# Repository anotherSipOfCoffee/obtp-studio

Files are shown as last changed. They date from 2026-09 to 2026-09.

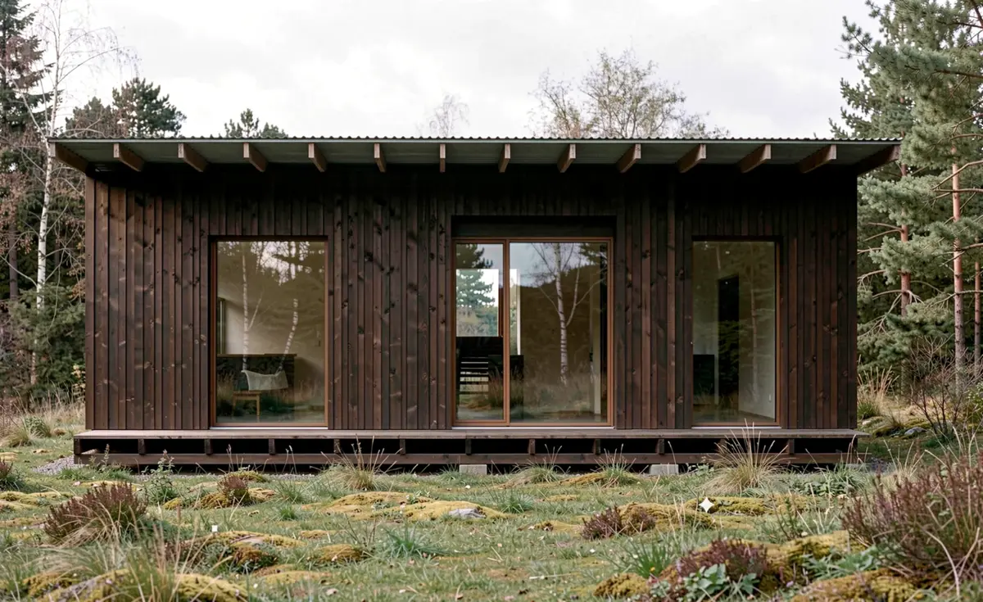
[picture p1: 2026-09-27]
dist/marketing/assets/s1-front.webp

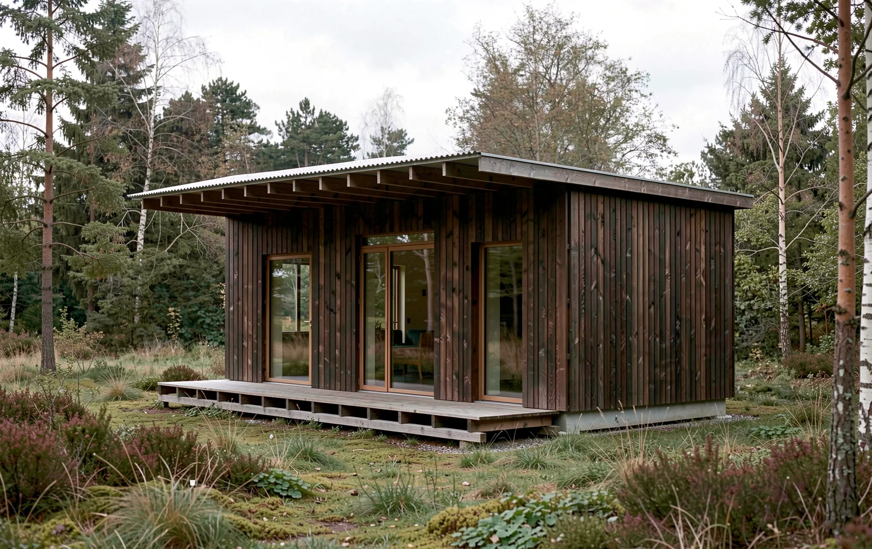
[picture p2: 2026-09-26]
dist/v3/images/studio-03.webp

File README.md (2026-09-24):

# OBTP Studio

Three variations in the selector: v1 original conceptual reference, v2 WikiHouse, v3 independent OBTP Cassette 01 research prototype. The default remains v2.

System is the source for v2/v3 geometry and assembly rules. system.lock.json pins its exact commit; tools/prepare_system.py verifies the checked-out commit and copies its dist tree to dist/system-source. Do not commit that reproducible copy. Studio v1 remains byte-identical to the pre-task reference.

Read 00_START_HERE.md and AGENTS.md for the Drive master / GitHub development policy. Changes are on dev/obtp-independent-v1-20260923; main/live are unchanged. The new read-only Check Studio development variations workflow builds and tests a downloadable preview, without deploying.

The existing Pages workflow publishes on main or manual execution. It is preserved but not authorized to run in this task. For local inspection of a prepared preview, serve its dist folder with python -m http.server 8765 --directory dist and open http://localhost:8765/#v3.

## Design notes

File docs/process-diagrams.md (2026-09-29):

# Process section — September 2026

Approved four diagrams originate in the owner-supplied `diagrams.3dm`. The SVG files retain projected model coordinates, uniform scale, original camera direction and arrangement; they are not AI-redrawn buildings. Diagram 01 has white, dark grey and light grey blocks. Other diagrams have neutral monochrome faces. Only geometry display and website copy changed. No change to System pin, presets, geometry outputs or PDF generation.

The four steps describe the intended product route, with production/delivery still in development. The page retains its wider development and occupancy notes. LT/EN shares the configurator language preference. Homepage defaults to Lithuanian when no preference is saved.

Configurator shows two active presets and four locked parameter previews: size, extension, sloped roof (No selected), terrace (Yes selected). Both selected and alternative parameter buttons are hatched. Public model values remain unchanged.

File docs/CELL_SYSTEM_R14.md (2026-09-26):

# Integrated cell system and previous-system comparison

Studio consumes the R14 canonical System export. The current model uses 900 × 1200 planning cells and a regular support lattice shared by building and terrace. Geometry and comparison quantities are generated in Python, never in Studio JavaScript.

Additional information now compares the selected new and previous configurations: structural footprint, wall assemblies, physical wood parts, geometric wood types and foundation support count. Links open actual model-derived plans for both. The named sizes no longer imply equal footprints; the comparison says so explicitly. No cost, speed or manufacturing-equivalence claims are made.

Existing configuration choice controls, Lithuanian default, white model presentation, disabled PDFs and two website roof options remain. Studio v1 and WikiHouse are preserved. Source pin changes require the System suite and Studio/browser checks; native Rhino acceptance and structural engineering remain separate.

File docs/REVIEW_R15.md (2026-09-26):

# studio 9120 — R16 review

Pins canonical System 0df918f23ed5cebb24259104ad7aa93918e5c1a9. System PR #20 and Studio PR #37 remain unmerged and unpublished.

Shared catalogue candidates: original 459 → first cells 381 → revised 319 (30.5% below original). Sauna 296 → 251 → 227 (23.3%); Studio 246 → 226 → 216 (12.2%). The 75% goal is not achieved. Previous opening revision: 358; geometry repairs alone: 370; shared cuts: 319 at unchanged footprints (13.8%). Same-first-cell-footprint revised: 340, separating resizing from construction changes.

Default complete M buildings: Sauna 121 types / 1063 primary pieces; Studio 137 / 1354. Shared cuts add 109 / 137 pieces and three / four default-building types versus repairs only. Catalogue reuse has an assembly cost. Facade remains visible and separately scheduled; no additional category is excluded.

Standard bays and plans remain; alternative grids created more variants. Selected lining extensions, facade battens and roof rails share supported lengths. Both widths remain 2400 mm. Terrace boards run consistently through returns. Repairs clear deck trims, niche facade overlaps and Studio glazing/head intersections. Connections and structural capacities remain unverified.

System review-r15/SHARED_KIT.md contains results, trials, primary source guidance and engineering holds. Its generated standalone review includes model-derived plans, six interactive models and cut comparisons. Studio consumes pinned outputs without duplicate geometry formulas.

Customer branding is studio 9120. Retain Lithuanian default, Plokščias, existing parameters, Main-first navigation, disabled PDF, no gable and normal GH preview. Drive and Architecture unchanged.

Final System suite: 51 tests passed, including supported joints, all-wood clashes, glazing clearances and export contracts. Non-deploying Studio CI compiles 216 browser configurations and 12 portable Rhino exports, tests browser behaviour and captures screenshots. Native Rhino/GH and engineering acceptance remain open.

The workflow provides studio-development-preview and visual-review artifacts. Serve the complete dist directory locally; generated review/index.html opens standalone. Production hosting is unchanged.

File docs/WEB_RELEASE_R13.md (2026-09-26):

# Website controls and PDF pause — 2026-09-26

Owner requests supersede the earlier three-roof/PDF release policy:

- Disable website PDF generation and show all four PDF downloads as disabled.
  The GH download also excludes PDF proofs. SVG plans and Rhino models remain.
- Remove the gable roof choice for both Studio and Sauna. The website exports
  216 flat/single-slope configurations. Native GH gable geometry is preserved.
- Translate Flat as Plokščias in Lithuanian.
- Use the existing choice-button design for configuration parameters, including
  preset, foundation and assembly system. Preserve disabled supplier alternatives.
- Remove the façade section because only one finish is supported; the fixed
  underlying facade value remains unchanged.

The verified export cache/progress changes from PR #36 are retained and adapted
to reject PDF-enabled catalogues. Regeneration still runs when the System pin,
runtime or exporter preparation changes. The earlier 19m17s measurement describes
R12 with PDFs; it is not a prediction for this PDF-free release.

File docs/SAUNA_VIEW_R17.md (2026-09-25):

# Sauna viewer R17

25 September 2026.

- Restored generated plywood panels. System owns the geometry and remains the only source of structural dimensions.
- Removed Generated plan from the viewer. The six submitted monochrome plans remain untouched.
- The submitted plan is contained in a fixed viewport without inner scrollbars. Aspect ratio and source line weights are preserved. This is a screen preview, not a promise of paper/physical drawing scale.
- Added a 90° rotation button for 3D and Cut. Orientation persists through layer and size changes; Reset returns to the original fixed view. Plan rotation is disabled to retain source orientation.
- No source geometry was rounded or snapped. Whole-millimetre dimensions and bounded decimal quantities are displayed; 4,572 mm is still a real legacy module dimension, not floating-point noise. Its quarter is 1,143 mm. Replacing that subdivision needs a different cassette width, not cosmetic rounding.
- New System opening and off-axis partition support reviews are linked through the existing System inspector. They remain design-development objects; the Sauna shell is not labelled as matching the source plans.

## Decision needed for the next geometry release

Use the owner's narrow Sauna layout as the authority and replace the legacy 4,572 mm transverse floor/roof with a narrow cassette. A candidate is 1,800 mm clear room depth plus the actual System wall buildup, retaining 600 mm planning increments along the length. This changes floor/roof geometry, perimeter support and connections; it must not be disguised as a rounding fix. Confirm exact datum (clear finished room, structural inside face or wall axis) before adapting all six plans. Actual wall/finish thickness then changes exterior dimensions rather than eroding the chosen clear room depth.

The user's earlier requirement to consult before correcting source-plan grid/connection mismatches remains in effect. Do not place doors into the mismatched earlier shell just to make them appear.

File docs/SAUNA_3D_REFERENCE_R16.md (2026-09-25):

# Owner 3D reference to System comparison · R16

The owner-provided `3d.3dm` is a **metre-unit** Rhino file with 151 objects on “Structural - Bearing” and “Interior - Furniture”. Its repeated L + side-bay shell references an approximately 6.2 × 2.0 m footprint, 3.0 m wall meshes and a 0.2 m slab envelope. It includes a transverse room partition, example door instances, separate heater/shower fixtures and sauna bench objects. It is a visual/layout reference; its meshes, wall solids and floor are not the OBTP System cassette.

The pinned System cassette controls build dimensions: 4,572 mm external transverse width, 195 mm wall depth, 220 mm structural floor joists plus 18 mm upper plywood, and 2,100 mm wall cassettes in the Studio configuration. Its optional foundation study sits below assumed grade. Studio shows structural cassette colors from System and generic gray for planning objects; generated upper and foot benches now have separate slats and supports rather than solid seat blocks, approximately 900/450 mm seat levels above the generated floor. This is a placement representation, not detailed bench construction or an approved anchorage.

The six `batches.dxf` plans have drawn outside depth about 2,000 mm and indicative ~100 mm walls. These **do not** follow the System's 4,572 mm outside width or 195 mm wall depth. Studio preserves those plans at native vector drawing scale as an owner-solved reference and labels the 4,572 mm generated model separately. No edit to the owner's room widths, doors or storage connection has been made under an invented fit. The modeled plans cannot yet be sold as six buildable cassette outputs.

A correct final generated floor plan and 3D Sauna require choosing either a narrower engineered System cassette family (including revised floor, roof and supports), or a new plan arrangement inside the 4,572 mm cassette. The 2,572 mm gross width difference is a program decision, not a drawing tolerance. Further design must resolve room widths, side storage enclosed area, door and glazing structure, sauna thermal envelope and site-specific foundation. See System `docs/cassette/FOUNDATION_AND_OPENING_STUDY.md` for foundation and aperture status.

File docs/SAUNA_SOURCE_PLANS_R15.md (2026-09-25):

# Sauna R15 · owner-solved six-plan reference

This version of Studio shows the six plans from the owner's `batches.dxf` as **monochrome vector drawings** with their source line weights. Select Sauna → S/M/L → optional storage, then open **Solved plan**. These are the submitted plan lines, sorted into three size rows and two storage columns; no wall, door, bench or shower geometry is altered. Their source drawing is in millimetres. The original uploaded DXF is deliberately not included in the public site; the six SVG extracts contain only visible plan geometry.

| Size | Main nominal interior length | Sauna length | Entrance length | Nominal clear depth | Sketched outer width/depth | Storage side bay |
| --- | ---: | ---: | ---: | ---: | ---: | ---: |
| S | 3,600 mm | 2,400 mm | 1,200 mm | 1,800 mm | 3,800 × 2,000 mm | +1,200 mm if on |
| M | 4,200 mm | 2,400 mm | 1,800 mm | 1,800 mm | 4,400 × 2,000 mm | +1,200 mm if on |
| L | 4,800 mm | 2,400 mm | 2,400 mm | 1,800 mm | 5,000 × 2,000 mm | +1,200 mm if on |

The main interior lengths and side bay follow 600 mm steps exactly. Sketched wall widths are about 100 mm and define boundaries, not engineered cassette thicknesses. The hot room stays a nominal 2.4 m long in all three sizes; the entrance area grows. The source linework includes two sauna bench layers, a heater footprint, entry swings and, for storage-on, a dry side room, outdoor bench and shower fixture. The left/right column and top/middle/bottom row classification is checked against the source's entity groups.

## Integration gap to decide with owner

The pinned System Cassette 01 shell is fixed at **4,572 mm outside width**, with about **4,182 mm clear**. The owner-drawn plan is about **2,000 mm outside depth**. Rotating its length onto Studio's repeated-bay axis does not solve the transverse mismatch: there would be about **2,572 mm outside-width difference**, far beyond nominal wall-thickness adjustment. The earlier generated Sauna model also varies hot-room length with size, whereas these drawings keep the hot room fixed and grow the entrance. Its optional side store is not generated by the cassette floor, exterior walls or roof. The old model view, its area/height/span screen and R14 CAD download therefore refer only to that earlier cassette study; they must not be taken as validation of the solved drawings. These are not structural construction details.

**Consultation before correcting geometry or connections:** choose whether the solved six plans should remain a 2D plan family while a narrow Cassette 01 width is researched later, or whether Studio should reserve the existing 4.572 m width and the owner wants to allocate the large residual strip in each plan. A genuinely narrower cassette and its floor/roof/bearing details belong to System, which the owner asked to pause. The building-area classification of any constructed side bay, plus actual support spacing, height, waterproofing, heater clearances and wall connections, must be rechecked once the construction geometry is chosen. No permit exemption follows from the plan study alone.

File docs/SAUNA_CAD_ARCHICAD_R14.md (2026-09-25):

# Sauna CAD R14 · complete DXF for Archicad import

Archicad reported the earlier lightweight R13 file as damaged. Its layer table had an invalid handle; ezdxf silently repaired that defect when reading, so the original parser-only check had missed it. This release reconstructs the source program geometry in a full AutoCAD 2010 ASCII DXF with standard drawing tables and explicit handles, then saves, reopens and audits every output. The seven R14 files have **zero audit errors and zero automatic fixes** after being written.

The [one-file six-plan correction set](../dist/v3/cad/r14/OBTP_Sauna_All_Six_Plans_Archicad_R14.dxf) includes S, M and L, each without and with side storage. Each variant is an individual CAD BLOCK referenced once in model space, in three rows and two columns, with a label above it. Units are millimetres. The six [separate R14 DXFs](../dist/v3/cad/r14/) are also linked from the Studio Sauna controls. `tools/export_sauna_archicad.py` generates both from the same `tools/export_sauna_variants.cjs` solver-derived drawings; it requires `ezdxf` 1.4.x. The browser downloads the generated, audited files instead of building minimal DXF text when clicked.

This repairs the known table defect and tests a second import parser. Archicad itself is not available in the build environment, so compatibility is pending a real import. The plans still contain proposed opening edges, accessory blocks, exterior shower and seat, and an unbuilt storage annex. They are correction studies, not construction drawings or a permit exemption claim.

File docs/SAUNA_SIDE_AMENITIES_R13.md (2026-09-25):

# Sauna R13 · three uses on the storage side

The six-plan correction set reuses one Cassette 01 shell for S/M/L, with optional storage off/on. The sauna and little hall stay side by side. M → L increases length by one 600 mm cassette, **without widening**. The shower remains outdoors on the hall/storage (east) side of the shell.

When storage is on, the exterior side is arranged in three parts: **1.2 × 1.2 m enclosed store** at the front/right of the hall; **900 × 900 mm outdoor shower** below it in plan; **900 × 450 mm outdoor seat** beside the shower toward the outer edge. The store has its own proposed outside door on its east face. Shower and seat remain open air; the store is an *unbuilt annex*, without generated floor, walls, roof, foundation or engineered attachment. None of the door openings is built. This is a spatial correction study, not a valid storage-on structural output.

[Home Made Sauna's Värme](https://homemadesauna.com/products/sauna-varme) is the precedent for grouping washing, dry storage and outdoor sitting around one exterior patio. Its actual plan, covered void, dimensions and construction are **not** copied. Our seat is an open-air study next to the shower and does not imply a covered patio.

| Size | Hot room nominal | Hall nominal | Bays with either storage setting | Shell outside-wall area | Conservative bound with three-part side study |
| --- | --- | --- | ---: | ---: | ---: |
| S | 2.4 × 1.8 m | 1.2 × 1.8 m | 4 | 11.140704 m² | 16.958304 m² |
| M | 2.4 × 2.4 m | 1.2 × 2.4 m | 5 | 13.898304 m² | 21.155904 m² |
| L | 2.4 × 3.0 m | 1.2 × 3.0 m | 6 | 16.655904 m² | 25.353504 m² |

The conservative screening bound is `(shell outside width + 2,400 mm) × shell outside length`; it deliberately captures open side amenities as well as the store. The legal building-area measurement and possible exemptions for uncovered exterior features require a site-specific review. The generated shell is 2.576 m high with 4.572 m conservative support spacing; no annex structure is generated, so those figures do not validate its roof or support layout.

[Six-plan overview](SAUNA_SIDE_AMENITIES_R13.svg). The six CAD DXFs use millimetres and editable named equipment BLOCK/INSERTs, with shell, unbuilt store, proposed doors and exterior features on separate layers. A native DWG writer was unavailable in this environment. DXFs are correctly identified and can be opened and saved as DWG with compatible CAD software.

**Correction questions:** Should the side store join the hall wall or retain the small unbuilt gap? Does its east-facing exterior door face the intended approach? Is the seat in a usable position by the shower, or should it be farther from spray? Does S have enough outdoor access around the shower and seat? Drainage, frost protection, ventilation, heater safety, door clearances and site rules remain to be designed. Site and land-use conditions must be verified separately.

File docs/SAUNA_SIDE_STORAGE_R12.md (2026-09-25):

# Sauna R12 · side storage correction plans

The current Sauna UI has two inputs: S/M/L and optional side storage. All six options retain the same Cassette 01 shell and the same hot-room width (nominal 2.4 m). The shower is mandatory and outdoors; there is no indoor shower room or long corridor. The little entrance hall is beside the hot room. The optional 1.2 × 1.2 m store is **to the right of the hall, above the exterior shower in plan**, with a separate outside access proposal. Its exterior cassette floor, walls, roof, junction and access opening are **not generated**. Storage-on options are marked as research holds, not valid building outputs.

| Size | Sauna nominal width × length | Little hall nominal width × length | Cassette bays, storage off / on | Generated shell outside-wall plan area | Conservative shell + side annex rectangular bound |
| --- | --- | --- | ---: | ---: | ---: |
| S | 2.4 × 1.8 m | 1.2 × 1.8 m | 4 / 4 | 11.140704 m² | 14.776704 m² |
| M | 2.4 × 2.4 m | 1.2 × 2.4 m | 5 / 5 | 13.898304 m² | 18.434304 m² |
| L | 2.4 × 3.0 m | 1.2 × 3.0 m | 6 / 6 | 16.655904 m² | 22.091904 m² |

The last column is `(outside shell width + 1,500 mm) × outside shell length`, with the annex's intervening strip and unused length conservatively included. It screens the proposed layout against the 50 m² target. It is **not** a measured completed annex building area or a legal total floor area. Modelled shell height is 2.576 m; conservative roof support spacing is 4.572 m. Outdoor pad, structural foundations, future roof projections, regulatory building area classification and site conditions need separate review.

[Six-plan overview](SAUNA_SIDE_STORAGE_R12.svg) and the six editable DXF drawings use the same plan solver as the UI. CAD units are millimetres. Green/brown room boundaries are unbuilt partitions; the store boundary is on `ANNEX_UNBUILT`; shower and doors are candidates. CAD contains named equipment BLOCK/INSERT entities. A native DWG converter was unavailable in the current workspace, so these files are correctly identified as DXF and can be opened or saved as DWG with compatible CAD software. No DWG is simulated by renaming the file.

### Questions for the correction round

1. Is the side room at the intended edge and setback, or should it attach directly to the hall wall? Its current nominal west edge is 600 mm past the hall's east planning line; the actual outer shell ends about 114 mm before the store's west edge.
2. Should the store's independent exterior access remain on its east/right edge, or face the same front approach as the hall?
3. Is a 1.2 × 1.2 m store appropriately sized once wall linings, clear passage and shelving are considered?
4. For L, does extending only the sauna and little hall along the cassette length preserve sensible bench and heater positions? Heater model/clearances, ventilation, wet services and doors remain unverified.

This is an editable spatial study for review, not a construction or permit drawing. Site and land-use conditions must be verified separately.

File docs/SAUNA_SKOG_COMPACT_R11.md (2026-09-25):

# Sauna R11 · three compact sizes, optional rear storage, outside-only shower

Status: spatial planning candidates. This supersedes the current product choices from R09/R10; those studies remain as history. It reuses the same Cassette 01 shell and dimensional envelope gate. No residential program is introduced.

## Precedent and layout family

[Home Made Sauna's Skog](https://homemadesauna.com/products/sauna-skog) demonstrates a sauna hot room, changing area and exterior shower in a compact shell. We reuse that functional relationship, not its purchased drawings, structural system or proportions. The OBTP proposal has **one small hall at the front**, a hot room beside it, and an exterior-only shower reached from the hall side. There is no indoor shower or selectable corridor type.

The independent parameters are **size S/M/L** and **separate storage room yes/no**. When on, the shallow room is on the far side of the hot room from the entrance. It has its own rear outside door: retrieving dry stored items does not require crossing a heated room. Storage is 3.6 × 1.2 m (4.32 m²) on the nominal grid; this is a narrow full-width room, **not** a 0.4 × 0.5 m cupboard. If 4.32 m² remains too large for the brief, a genuinely smaller room needs a revised layout or a partitioned use for the remaining rear band.

[Compare all six nominal floor plans](SAUNA_SKOG_COMPACT_R11.svg). Brown dashed segments are proposed door edges; the blue square is the exterior shower study.

| Size | Hot room nominal | Hall nominal | Bays without / with storage | Exterior wall plan area without / with storage |
| --- | --- | --- | ---: | ---: |
| S | 2.4 × 1.8 m | 1.2 × 1.8 m | 4 / 6 | 11.140704 / 16.655904 m² |
| M | 2.4 × 2.4 m | 1.2 × 2.4 m | 5 / 7 | 13.898304 / 19.413504 m² |
| L | 2.4 × 3.0 m | 1.2 × 3.0 m | 6 / 8 | 16.655904 / 22.171104 m² |

The hall is only 2.16, 2.88 or 3.60 m² (nominal); it allows towels, slippers and standing indoors. With storage, the extra 1.2 m of length does not enlarge the hot room or hall. There are two proposed outside access edges without storage (main entry, shower) and three with storage (plus independent rear door). The rear store is an auxiliary non-residential space, not a bedroom or changing suite.

## Checks and unresolved details

The hot-room nominal volumes at the present 2.1 m clear height are 9.072, 12.096 and 15.12 m³. Preliminary heater references, *not installed heater specifications*, are [Harvia SW80](https://www.harvia.com/en/products/HSW800400M/the-wall-sw80-80-kw-blacksteel) at 7–12 m³ for S, [SW90](https://www.harvia.com/en/products/HSW900400M/the-wall-sw90-90-kw-blacksteel) at 8–14 m³ for M, and [Club K13.5G](https://www.harvia.com/en/products/HRKG135400/club-k135g-135-kw-steel) at 11–20 m³ for L. The L reference is a larger professional floor-mounted heater, so its footprint is drawn larger. Actual electrical supply, safety distances, manufacturer instructions, finished volume, ventilation, heater guards and bench anchorage need design.

All six nominal configurations pass the existing geometric solver's room, fixture, interior door swing, outside door edges and heater-volume screens. Generated shell height is 2.576 m and conservative roof support spacing 4.572 m. Outside-wall area is below 50.00 m². These are **dimensional checks only**; site and land-use permit conditions remain separate. The 900 × 900 mm unroofed shower pad remains outside the measured outside-wall rectangle, but future built screens, platforms or canopy may affect area classification.

The shell is 4.572 m in setting-out width, with about 4.182 m clear; the 3.6 m nominal planning grid leaves a strip between hall/storage boundaries and actual cassette wall. Doors shown at exterior wall edges are uncut proposals, not continuous finished passages. The nominal 1.2 m hall will narrow after partitions and linings. The rear storage is only 1.2 m deep before finishes. Physical access, frost protection, wastewater disposal, winter-safe footing and privacy must be solved before claiming functional or technical validation. DXF blocks, 3D accessory and linked plan are geometry studies, not fabrication documents.

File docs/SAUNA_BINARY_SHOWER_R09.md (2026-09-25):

# Sauna R09 · binary features and generated exterior shower study

Status: planning geometry only. One pinned OBTP System Cassette 01 shell still supplies the slab, walls, roof, joints and envelope measurements. Studio adds an unroofed fixture study outside its east wall. No wall opening, supply, drain, platform support, privacy screen or roof is generated.

## Controls and allowed combinations

Size remains S, M or L. The remaining features are binary: wet lobby on/off, full-pass corridor on/off, indoor shower on/off and exterior wall shower on/off. One shower must remain on. Wet lobby and through corridor exclude one another. Both circulation features are unavailable at S and M; full-pass is unavailable with an exterior shower because its two end accesses plus the shower access have no screened site route. For L, both circulation features off selects a shared-changing plan. Switching size or shower mode selects a complete tested grid allocation; it cannot leave hidden lengths from an older layout.

| Size | Indoor only / both: modules, outside-wall area | Outdoor only: modules, outside-wall area | Exterior-only wet transition |
|---|---|---|---|
| S | 9, 24.93 m² | 8, 22.17 m² | 1.8 × 1.8 m; changing 6.48 m² is below the 2× advisory comparison, so occupancy needs a furnished trial. |
| M | 11, 30.44 m² | 9, 24.93 m² | 1.8 × 1.8 m; changing 8.64 m². |
| L, wet lobby | 14, 38.72 m² | 12, 33.20 m² | 1.8 × 1.8 m plus a separate 3.6 × 1.2 m wet lobby. |
| L, shared | 14, 38.72 m² | 10, 27.69 m² | 1.8 × 1.8 m; no dedicated interior shower. |

L indoor/shared instead uses a 1.8 × 3.0 m hot block, 1.8 × 4.2 m wash block and 3.6 × 3.6 m changing block. L through retains the earlier two-access indoor-only research geometry. These allocations are nominal 600 mm grid cells, not finished room dimensions or authorized occupancy. The outside-wall building footprint cap remains based on System's wall bounds and is checked with the existing 50 m² / 5 m / 6 m hard generator gate.

## What is generated

For outdoor-only and combined washing, the solver places a 900 × 900 mm shower/pad reservation 100 mm outside the east exterior wall, an aligned candidate 900 mm access edge, and an unroofed study model with pad, riser, arm and shower head. The same reservation is drawn outside the shell in the linked plan and exported as a separate `OBTP_OUTDOOR_SHOWER_STUDY` DXF BLOCK on an exterior study layer. Outdoor-only removes the indoor shower fixture and relabels its former room as a small wet transition. The cassette wall itself remains intact; an access edge is a **proposal**, never a manufactured opening. No cover, screen or roof is included. The accessory is excluded from the current outside-wall building footprint calculation because it is an unroofed exterior study; classification and area effects of any built pad, screen, canopy or utility assembly require site-specific legal and design review.

The 3D study objects are visually distinguished from the System cassette frame and omitted from the material schedule. The cut view shows the existing structural section, and the plan/DXF carry the shower and candidate access. The CAD file describes planning BLOCK/INSERT geometry and can be opened in DWG-capable software; there is no native DWG or approved manufacture file.

## Functional and technical holds

An outdoor-only year-round plan remains **functionally unverified** even when the equipment rectangles fit. It needs finished wet threshold, wind and ice-safe circulation, sufficient shelter/privacy, frost-safe water supply, a proper wastewater destination and site approval. Adding an exterior shower alongside an indoor washing room is a spatial candidate only; exterior hardware/services are still unbuilt. The [North American Sauna Society's auxiliary-space guidance](https://www.saunasociety.org/blog/2018/4/12/design-of-auxiliary-spaces-in-a-sauna) describes 1.5× washing and 2× changing as comparisons, not legal minima; a specific outdoor fixture's [installation manual](https://www.frostline.dk/wp-content/uploads/2023/11/Monteringsvejledning-3080-11-2023-1.pdf) imposes drainage and frost constraints that this sketch does not satisfy by itself.

Before treating the exterior choice as a solved preset, finish door/threshold and sauna heat-loss design, select the shower product and winter service strategy, verify ground drainage and wastewater rules for the specific site, assess an exterior screen or canopy in the legal area measurement, and revisit all dimensions with finished assemblies. Site-specific Lithuanian permit conditions remain separate from dimensional compliance. Matrix remains a separate study.

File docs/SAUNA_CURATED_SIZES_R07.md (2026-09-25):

# Sauna R07 · curated sizes, circulation and shower strategy

Status: **research decision record, not a solved building or technical approval**. Keep Matrix as a separate geometric study/source. Preserve one System Cassette 01 structural generator for Sauna, Studio and Workshop; do not infer valid rooms from a module count.

## Finding

A raw 8–18 module slider produces many nominally legal shells but too many redundant or poorly proportioned sauna plans. Replace the primary Sauna module-count choice with a **curated whole-plan size** (S, M, L), selected after heater/bench/shower/door and occupancy fits. Keep the old count and Matrix grid for research or advanced inspection. Architecture's compact/generous selection is a catalogue of complete plans, not a continuous structural dimension slider; copy that *selection principle*, not its residential program or literal size count.

The shower is a **topology choice**, not simply a fixture visibility toggle:

| Shower strategy | Rooms / route to prove | Recommendation |
|---|---|---|
| Indoor dedicated | Hot room ↔ wet washing ↔ changing/rest; route and drying are checked together | First implementable baseline; existing sub-block solver expects this arrangement. |
| Exterior wall shower, no indoor wash room | Hot room, changing/rest, direct sheltered/wet transition to shower outside | Separate study branch. A real accessible shower route, frost protection, privacy, drainage, wastewater and wet/dry separation must be shown before calling this functionally valid. |
| Both | Full indoor arrangement plus optional outside rinse/cooling shower | Add after indoor baseline; the outside fixture does not replace internal washing capacity. |

An exterior shower without a dedicated enclosed room does **not** establish that its pad, screen or canopy has no effect on building area or site permissions. Check the exact built arrangement. The exterior plumbing and runoff likewise need site-specific review.

## Evidence and proportions

The [North American Sauna Society design guidelines](https://www.saunasociety.org/design-guidelines) call for convenient shower, changing and cooling/rest access and coordinated heater, door, bench and ventilation. Sauna designer Lassi A. Liikkanen's [auxiliary-space analysis](https://www.saunasociety.org/blog/2018/4/12/design-of-auxiliary-spaces-in-a-sauna) gives **washing ≈ 1.5 × hot room and dressing ≈ 2 × hot room** as advisory comparators, explicitly not legal minima. An [outdoor-shower sauna precedent](https://www.saunasociety.org/blog/2023/7/20/bringing-the-sauna-home-by-rick-watson) demonstrates feasibility, not proof that the same arrangement is functional in Lithuanian winter. A [frost-protected shower manufacturer's installation instructions](https://www.frostline.dk/wp-content/uploads/2023/11/Monteringsvejledning-3080-11-2023-1.pdf) require a dry, draining well and frost-safe supply; weather suitability depends on a selected product and installation.

The existing 600 mm planning grid is a **nominal program layer** inside a wider Cassette 01 shell, not a measured finished interior. In particular its six columns cover 3,600 mm, while exterior width is about 4,596 mm. Blocks, partitions and door projections remain studies; do not size equipment from nominal rectangles alone.

## Initial indoor catalogue to draw and stress-test

All numbers below are from the current pinned System generator at 2,100 mm nominal walls. External area is outside-wall bounding width × length, not the summed program blocks; height is actual generated 2,576 mm, support distance 4,572 mm. Each passes the existing **50 m² / 5 m / 6 m dimensional gate** and the current nominal sub-block solver. No real partitions, openings, wet floor or ventilation are constructed, so **none has technical approval**.

| Size / provisional brief | Cassette modules | Circulation | Hot / wash / change / other nominal grid areas (m²) | Outside-wall area / internal clear shell (m²) | Research judgment |
|---|---:|---|---|---|---|
| S · compact one-entry | 9 | Shared changing | 4.32 / 4.32 / 8.64 / 0 | 24.93 / 20.95 | Better changing proportion than existing 8-module trial; wash still below 1.5× guidance. Test wet approach and dry seat. |
| M · one-entry with larger wash | 11 | Shared changing | 4.32 / 6.48 / 8.64 / 2.16 service | 30.44 / 25.97 | Both advisory wash and changing ratios fit nominally. Service strip needs a real purpose and access, and wet circulation needs finished fit. |
| L · wet lobby and changing | 14 | Wet lobby | 4.32 / 6.48 / 10.80 / 4.32 lobby + 2.16 service | 38.72 / 33.50 | Better wet/dry separation in plan. Current wet-lobby sub-block study draws two exterior access candidates; redesign as one outside entry by default before promoting it. |

The older 10-module shared default gives 4.32 / 4.32 / 10.80 m², so its extra length enlarges changing while washing stays small. A 14-module side-through corridor consumes **9.36 m² nominal grid area**, leaving changing at 7.20 m² for one tested 4.32 m² hot-room layout; it has a nominal sub-block fit but weaker priorities for an ordinary small sauna. This supports a **site-conditional through variant**, never an automatic L default.

These S/M/L labels indicate **complete programs**, not fixed universal capacities or an automatic 9/11/14 mapping across shower strategies. An exterior-only shell would need its own block graph and fit study. “Both” may reuse an approved indoor shell only after the exterior connection passes its own gates. None of these numbers is a permitted occupancy claim.

## Proposed product controls and validity rules

1. Sauna controls: **Size: S / M / L**, **Circulation: direct/shared / wet lobby / through (only if a two-access site brief exists)**, **Shower: indoor / outdoor wall / both**. Do not expose every Cartesian combination: define compatible complete templates and explain unavailable choices.
2. The default should be an indoor one-entry plan. One entry is also the starting assumption for a wet lobby. Keep two outside accesses as a deliberate site option; “through” means a real continuous path with two useful exterior exits, not two door icons.
3. Show the chosen layout's nominal room dimensions and generated outside-wall building area, clear shell area, calculated height, and maximum support spacing. Preserve the hard regulatory gate in the shared generator for all three program presets. An exterior canopy/screen/pad or changed roof must trigger fresh measurements and review.
4. Functional gate: required spaces exist; equipment and door candidate fit finished faces and their swings; no wet traffic forced across a dry seat; changing has believable occupancy and storage; sauna ↔ shower ↔ cooling/rest route works in all intended seasons; heater volume, bench access, moisture separation and ventilation are checked. Advisory 1.5×/2× proportions should prompt explicit assessment, not masquerade as regulations.
5. Technical gate stays false until a real wall opening system, partition assembly, shower drainage/waterproofing, electrical/heater installation, ventilation and exterior water/wastewater treatment are designed and verified. Never badge a nominal block plan as a solved building.

## Test sequence and open decisions

- Draw S, M, L indoor plans at **finished dimensions** and place actual swinging doors, bench heights, heater protection, one shower user, towels and changing seats. Compare one-entry wet lobby to the current two-entry drawing.
- Prototype outdoor-only as a *different program graph* that removes the indoor wash room and tests the exterior route. Establish year-round versus seasonal use, required privacy/shelter, water supply and wastewater concept before accepting a smaller shell.
- Prototype “both” only once the indoor plan works, showing the exterior shower as additional seasonal/cooling access. Recompute the building envelope for any built exterior additions.
- Retain a through corridor only for an explicit site route requirement; test both external doors as actual supported openings.
- Freeze the shortest **functionally passing** complete templates, then connect S/M/L selection to the same Cassette 01 generator. Re-run dimensional, sub-block, switching, DXF and rendered-plan tests. Keep Matrix outside the Sauna product catalogue.

Unresolved: intended simultaneous users; year-round exterior washing versus seasonal cooling; site access; wastewater and frost protection; finished wall thickness and actual opening structure; whether an outdoor canopy/screen/pad is built and how it is measured in the local regulatory area. The existing LT I-group dimensional envelope is a project constraint, **not a universal permit exemption**; site and land-use conditions remain separate.

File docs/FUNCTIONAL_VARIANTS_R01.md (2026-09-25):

# Functional variant screen R01 · Sauna and Studio

Status: **research screen, not a design approval**. Generated envelope compliance is separate from functional suitability. No Studio v3 variation has a built exterior door, window, interior partition, sauna enclosure, shower, extraction or services; `technicalValid` remains false for Sauna. This study uses a small non-residential private sauna and a one-person clean design/work studio as explicit briefs. Different occupancy, washing practices or site access can change the ranking.

## Evidence and rule

Finnish-style bathing cycles between the heated room, washing/cooling and rest. The [North American Sauna Society's design guidance](https://www.saunasociety.org/design-guidelines) calls for convenient access to shower, changing and cooling/rest, and for heater, door, benches and vents to work together. Finnish sauna designer Lassi A. Liikkanen's [auxiliary-space study](https://www.saunasociety.org/blog/2018/4/12/design-of-auxiliary-spaces-in-a-sauna) uses **1.5× hot-room area for washing and 2× for changing as rules of thumb**, and cautions that more people may occupy auxiliary rooms than the hot room at one time. These are *comparators*, not Finnish or Lithuanian statutory minima. [Sun Sauna's planning advice](https://sunsauna.fi/en/blog/the-right-place-for-the-heater-and-the-door-in-the-sauna-room/) starts door placement from the bench/heater arrangement **and the shower-side layout**. The [Finnish Sauna Society's wet-room discussion](https://sauna.fi/saunatietoa/saunan-rakentaminen-ja-kaytto/saunan-rakennevaatimukset/) requires careful detailing of moisture and the sauna–washing interface.

We screen in this order:

1. **Geometry gate:** existing generated outside-wall area ≤ 50 m², modeled height ≤ 5 m, modeled support span ≤ 6 m. Failure prevents generation, as before.
2. **Task and adjacency gate:** for Sauna allocate distinct heat, washing and changing/rest; consider the actual path sauna ↔ shower ↔ rest and outside, plus whether wet traffic crosses a proposed dry seat. For this comparison a hot room below 1.8 × 1.8 m or a washing block below 1.8 × 1.8 m is screened out for the *current* heater/bench and shower-approach exercise. The 1.8 m study values are project assumptions, not code requirements. A current reference heater outside its nominal volume range is also screened out for that equipment. For Studio the one-person desk brief uses 10 m² of unpartitioned internal clear area as a lower research benchmark; smaller hobby uses may be evaluated separately.
3. **Unbuilt technical gate:** door positions/swings, bench/heater clearances, thermal/moisture assemblies, drains, ventilation, daylight, actual finished room sizes and structural openings. Even a spatial candidate stays **unverified** here. Never score mere block overlap or nominal area as a solved room.

The [Finnish Institute of Occupational Health](https://www.ttl.fi/oppimateriaalit/ergonomian-tietopankki/toimisto-ja-tietotyo) gives 10–12 m² as *recommended* for a one-person assigned office room, and stresses matching area to work and equipment. It is a comparison for a clean desk Studio, not a Lithuanian minimum. Workplace [lighting](https://www.ttl.fi/teemat/tyoturvallisuus/tyoturvallisuuslain-soveltamisopas/tyota-ja-tyoolosuhteita-koskevat-tarkemmat-saannokset/34-ss-tyopaikan-valaistus) must respond to the task and avoid glare. An art practice using coatings/aerosols needs task-specific extraction; [NIOSH](https://www.cdc.gov/niosh/engcontrols/ecd/detail30.html) describes local exhaust for paint and coating processes. Do not treat a window as proof of sufficient extraction.

## Run against existing 600 mm Cassette 01 options

Metrics below are from the **current System generator**, with the shared 4,572 mm setting-out width, 2,100 mm nominal wall height and outside-wall skins measured. Sauna block areas are **nominal grid allocations**, not finished rooms. The 10-module corridor variants use their 3+3 row defaults; a direct generator call previously fell through to the shared-layout 4+4 defaults and failed. The generator default is now corrected to match the UI.

| Sauna option | Modules | Outside-wall area | Heat / washing / changing | Extra route | Research judgment for this brief |
|---|---:|---:|---:|---:|---|
| Shared changing, one entry | 8 | 22.17 m² | 4.32 / 4.32 / 6.48 m² | none | Compact spatial candidate for few users; changing is below 2× heuristic, and wet users return through changing. |
| Shared changing, one entry | 10 | 27.69 m² | 4.32 / 4.32 / 10.80 m² | none | **Best current compact one-entry comparison**, pending a direct washing–sauna door and credible dry/wet interface. |
| Shared changing, two side entries | 10 | 27.69 m² | 4.32 / 4.32 / 10.80 m² | dry crossing through changing | Use only if two site accesses have a defined purpose; second structural opening/privacy burden brings no general private-sauna advantage. |
| Dead-end side corridor | 10 | 27.69 m² | 4.32 / 4.32 / 4.32 m² | 6.48 m² corridor | Spatially possible, but small changing/rest and large route allocation; rotated heater/bench fit not shown. Lower priority for an ordinary one-entry sauna. |
| Full-pass side corridor | 10 | 27.69 m² | 4.32 / 4.32 / 4.32 m² | 6.48 m² corridor | Purposeful **only when both end accesses and an independent through route are requirements**; rotated equipment layout and end-wall openings unresolved. |
| Wet lobby, two side entries | 12 | 33.20 m² | 4.32 / 4.32 / 10.80 m² | 4.32 m² wet landing | **Best current dry-changing spatial comparison** if separated wet circulation is needed; second exterior access is optional at concept level, but the current study draws two candidates. Waterproofing and actual door operations unresolved. |

None earns a technical pass. All have washing equal in area to the 4.32 m² hot room, below the **1.5× advisory**. That fact calls for a shower-use and equipment check, not an automatic rejection. A longer building with the original small wet rooms is not automatically better: for example 12-module shared changing grows to 15.12 m² while heat/washing remain 4.32 m² each. The 12-module wet lobby instead puts the extra 4.32 m² into separating the wet approaches. These comparisons explain the conditional recommendations; they are not numeric scores claiming building performance.

An exhaustive pass through 8–18 modules, five circulation choices, allowed widths and 2–15-row wet-room lengths finds **9,024 geometrically allocated parameter states**. The current heater-volume, minimum study-block and changing-area screens retain **664 spatial candidates**. These counts are *parameter combinations*, with many nearly identical plans; they do not mean 664 validated sauna designs. The remaining candidates still fail the unbuilt technical gate. The automated test records this coverage so changing the controls cannot silently turn obviously undersized room allocations into a functional pass.

The subsequent [R06 generative sub-block solver](SAUNA_SUBBLOCKS_R06.md) places the heater, bench, shower, seat and adjacent door candidates and rejects a further **11** of those 664 nominal candidates, leaving **653 geometric placement candidates**. That additional screen still cannot verify real openings, finished circulation or technical assemblies.

**Next Sauna test:** draw a single-entry heat ↔ washing ↔ changing/rest route using the ten-module shared shell; place a *candidate* direct sauna–washing door without colliding with the R02 heater, bench, shower and exhaust route. Compare its finished circulation against the 12-module wet-lobby proposal. Retain a second outside access or full-pass corridor only for a site brief that actually needs it. No exterior wall is cut until the structural-opening hold is resolved.

## Studio start

| Modules | Outside-wall area | Unpartitioned clear area | One-person clean desk brief |
|---:|---:|---:|---|
| 4 (current default) | 11.14 m² | 8.41 m² | Below the chosen 10 m² benchmark; do not present as a generally workable one-person desk Studio. Could suit a specific compact hobby task after a furniture test. |
| 5 | 13.90 m² | 10.92 m² | First spatial candidate for one dedicated desk. Test desk, chair movement, door approach and storage. |
| 6 | 16.66 m² | 13.42 m² | Better first detailed layout trial, allowing more margin for a real access and storage arrangement. |
| 8 | 22.17 m² | 18.44 m² | Candidate for larger drawing/art tables or two activities, pending task-specific equipment, lighting, extraction and service needs. |

The Studio currently has **no real windows or doors** because source opening instructions and structural details are on hold. The research screen therefore checks clear area only and marks every Studio spatial candidate as *unverified*, never a furnished or daylit working room. Next, define two task briefs—clean desk/design and dry art/table work—then draw actual workstation, access and storage envelopes at 5, 6 and 8 modules. Wet/solvent-based art is a separate ventilation/service review, not an automatic variant of the desk plan.

## Implementation boundary

`dist/v3/function-screen.js` applies only these explicit **brief-specific** spatial checks. It reports reasons and unresolved holds in Studio v3. It does **not** disable otherwise valid structural geometry or turn advisory ratios into regulations. The generator's dimensional constraints remain hard; functional results cannot override them. A final room classification requires finished dimensional/door/equipment evidence and engineering, not a heuristic score.

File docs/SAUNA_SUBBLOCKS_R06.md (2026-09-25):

# Sauna R06 · generative equipment and door sub-blocks

Status: **parametric CAD planning study** on top of the same System Cassette 01 shell. Nothing here cuts a wall or builds a partition, bench, shower, heater mount or wet floor. The solver enumerates candidate *adjacent room edges* and offsets; it never rotates a fixed R02 sketch onto an incompatible plan or marks the technical Sauna as solved. It drives the linked floor-plan overlay and a downloadable CAD file for each compatible configuration.

## Researched adjacency rules

| Sub-block | Candidate wall relationship | Placement and rejection rule |
|---|---|---|
| Sauna door | Prefer the shared Sauna–washing partition in the compact one-entry layout; open **out of the Sauna** into washing. In wet-lobby and side-corridor variants, open toward the selected adjoining access block. | Detect a real shared grid edge, find a nominal 800 mm edge span with 150 mm end reservations, and fit a full 800 × 800 mm conservative swing envelope inside the receiving block. Try offsets at 100 mm steps; reject if any receiving-room equipment/swing intersects. Sauna-door outward motion and no lock follow [Finlandia Sauna](https://finlandiasauna.com/specifications/sauna-door/). This is not a Lithuanian door width or egress certification. |
| Heater | Wall opposite a side-entry edge; side wall away from a front-entry edge. | Use the [Harvia SW80](https://www.harvia.com/en/products/HSW800400M/the-wall-sw80-80-kw-blacksteel) published **260 mm depth × 430 mm width**, **7–12 m³** nominal volume range. Move the heater along the front wall of a shallow room until its study approach zone does not overlap the foot bench; reserve an unverified 300 mm no-touch approach zone. Manufacturer safety/installation clearances, actual heated volume, electrical supply and guard must be checked against the current manual. |
| Upper bench | Opposite the entry/front side, along the rear room face. | 600 mm nominal depth, 60 mm *hypothetical* offset from planning boundaries. [Harvia's bench guidance](https://www.harvia.com/en/ideas-and-trends/products/choosing-sauna-benches/) suggests at least 500 mm seat depth, about 600 mm per sitter, 1,100–1,200 mm headroom to ceiling and about 350 mm steps. No support anchorage or actual seat capacity is certified. |
| Foot bench | Immediately before the rear upper bench, stopping short of the entry side to preserve a nominal approach strip. | 450 mm study depth; reject heater or approach-zone overlap. Bench elevation and guard are unbuilt. |
| Shower | Far side/rear of the washing block, away from the preferred Sauna door swing. | 900 × 900 mm reservation, consistent with a common [manufacturer tray dimension](https://files.cdn.kaldewei.com/data/sprachen/englisch/prospekte/rest/Steel_Enamel_Baths_and_Shower_Trays.pdf); not a selected product. Full shower use, screened splash, drain, falls, waterproofing and service route remain unverified. |
| Changing seat | Rear/side of the changing/rest block, away from the default front entry and the preferred washing/lobby door swing. | 1,200 × 550 mm study rectangle; no occupancy or furniture compliance claim. |
| Outside access | Front changing wall in the one-entry variant; paired side positions in the two-access variants; front/rear of the corridor when full-pass is selected. | 900 mm candidate edge, projected from the program grid onto the actual exterior shell in Plan and CAD. The grid has a **486 mm transverse offset** at ten/twelve modules relative to the modeled 4,572 mm shell. The connecting jamb/partition and structural opening are unbuilt. This projection must not be mistaken for an approved wall cut. |

The designer's [door/bench/heater advice](https://sunsauna.fi/en/blog/the-right-place-for-the-heater-and-the-door-in-the-sauna-room/) explains why these decisions are coupled and why the shower-side furniture must be considered before choosing a sauna door. The [Finnish Sauna Society](https://sauna.fi/saunatietoa/saunan-rakentaminen-ja-kaytto/saunan-rakennevaatimukset/) also calls attention to the moisture-sensitive Sauna–washing partition. No ventilation opening is generated: [Harvia's ventilation guidance](https://support.harvia.com/hc/en-gb/articles/21953036825628-Ventilation-in-the-sauna) requires a scheme matched to heater, exhaust and temperature sensor rather than a universal hole position.

## Actual generative trials

All coordinates below are nominal millimetres measured from the **program grid**, front west corner. The shell remains larger; the CAD exporter positions the grid inside System's outside dimensions. These trials are recalculated whenever the Sauna module count, wet-block width/length or circulation study changes.

| Brief | Heat → washing/changing route | Heater body | Upper bench | Shower | Result |
|---|---|---|---|---|---|
| 10 modules, shared one-entry | Sauna → washing → changing; direct partition door at x=1,800, y=3,250–4,050 | x=60–320, y=3,320–3,750 (west wall) | x=60–1,740, y=4,740–5,340 | x=2,640–3,540, y=4,440–5,340 | Nominal spatial fit; changes the R02 heater wall because the Sauna door now faces washing. |
| 12 modules, wet lobby | Sauna → wet lobby → changing; washing → wet lobby; three separate interior door candidates | x=60–320, y=4,520–4,950 | x=60–1,740, y=5,940–6,540 | x=2,640–3,540, y=5,640–6,540 | Nominal spatial fit with distinct wet landing; two outside side-door candidates remain site dependent. |
| 10 modules, full-pass | Sauna, washing and changing open to a 1,200 mm allocated corridor | x=3,280–3,540, y=3,770–4,200 | x=1,260–3,540, y=4,740–5,340 | x=2,640–3,540, y=2,640–3,540 | Nominal fit after heater moves toward the front of the shallower 2,400 × 1,800 mm Sauna. Bench, corridor finished width and both end-wall entries need detailed testing. |

The 100 mm offset search and 40 mm candidate swing buffer are **planning tolerances**, not code clearances. The solver checks nominal room containment, equipment overlaps, receiving-room swing squares, reference volume and room adjacency. It fails with a reason when these simple constraints cannot fit. Subsequent finished-wall thickness, door-leaf/jamb geometry, seat heights, user count, heater installation distance and real wet circulation can overturn any candidate.

## CAD delivery

- [10-module one-entry CAD blocks](../dist/v3/cad/sauna-10-shared-r06.dxf)
- [12-module wet-lobby CAD blocks](../dist/v3/cad/sauna-12-wet-lobby-r06.dxf)

The **Download CAD blocks · DXF** button in Studio v3 generates the current Sauna configuration from the same sub-block solution. Files are millimetre [DXF drawings with six named reusable `BLOCK` definitions and placed `INSERT` references](https://help.autodesk.com/cloudhelp/2021/ENU/AutoCAD-DXF/files/GUID-28FA4CFB-9D5E-4880-9F11-36C97578252F.htm); shell and program lines are separate reference layers. A CAD editor can open the DXF and save it as **DWG**, but this environment has no verified DWG writer. No `.dwg` binary is produced or mislabelled. The two checked-in samples were opened with ezdxf and verified to contain six named OBTP blocks, 8 and 10 placed references respectively, and millimetre drawing units.

Before moving any candidate to construction geometry, specify finished room assemblies and a selected heater manual; resolve the cassette wall-opening and header/jamb connections; detail waterproofing, drainage and ventilation; redraw the door swings at finished faces; and re-run the three-dimensional regulatory envelope and site review. The presently generated building shell and its hard dimensional screen are unchanged.

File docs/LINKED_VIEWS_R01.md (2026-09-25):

# Studio v3 linked views R01

Studio v3 now presents 3D, Cut and Plan as views of one System-generated cassette configuration. Changing the preset, cassette count, layer or Sauna program dimensions updates the same configuration in the active view. The plan is a horizontal section of the generated, skinned exterior wall assets at **1,100 mm above the modeled floor surface** (floor surface Z = 238 mm; section Z = 1,338 mm). It draws each wall asset intersection from its world bounds. Sauna program rectangles use the same plan's 600 mm grid and are centered within the modeled footprint; dashed lines designate **unbuilt planning allowances**, not partitions or doors.

The Cut view clips the rendered structural frame at the same Z = 1,338 mm plane and hides roof cassette objects. It is a display-only derivative; the full source scene, schedules and envelope checks remain unchanged. It does not add a section cap, wall assembly, access opening, waterproofing, or technical installation. System still owns source geometry and placement. The camera holds a 45° plan angle and fixed elevation across 3D/Cut, with wheel zoom available and Reset returning to the fixed orientation.

The original 3D layer and exploded controls remain available. Plan always depicts the complete exterior wall section even when a subset of assembly layers is selected, so its underlying building outline remains linked to the generated full configuration. The plan coordinates and modeled section are research geometry; they are not measured finished clear dimensions or approval drawings.

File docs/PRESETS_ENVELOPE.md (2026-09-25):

# Shared Studio presets and dimensional gate

## Sauna planning blocks · 25 September 2026

The Sauna control also offers **circulation plan studies** within the same preset: shared changing/rest with one proposed outside entry; shared changing/rest with two proposed side entries; a 1,200 mm nominal dead-end side corridor with one proposed outside entry; or the same corridor passing between two proposed end entries. The corridor studies allocate two grid columns to passage for the full `(module count − 1)` rows. The remaining four columns hold sequential changing, washing and Sauna blocks; each has at least two rows. In the ten-module R03 example, each room occupies 2,400 × 1,800 mm and the corridor uses 6.48 m² of the 19.44 m² planning grid. Changing between shared and corridor studies keeps the current module count; shared block dimensions are restored when switching back, while corridor lengths are clamped to leave two changing rows. See [R03 manual comparison](SAUNA_CIRCULATION_R03.md). No exterior doors or interior corridor partitions are generated, and `plan.technicalValid` stays false for every circulation study.

An additional **two side entries + wet lobby** study follows [R05](SAUNA_WET_LOBBY_R05.md). Selecting it raises module count to at least **12**, reserves five 600 mm changing rows and two wet-lobby rows before the wet blocks, and restricts their step controls accordingly. It keeps the original two wet-block shapes at its default 3-column × 4-row allocation, with outside-wall area **33.201504 m²**. The lobby is a colored spatial block only: no waterproofed floor, partition, door or drain is generated. Leaving this study keeps the compatible current module count and available wet-block dimensions.

The Sauna preset now contains a two-dimensional program grid inside the existing Cassette 01 structure. The six-column grid is 3,600 mm wide and has `(module count − 1)` rows of 600 mm. It fits inside the generated 4,182 mm clear width and `(600 × module count − 390)` mm clear length. The remaining 582 mm across the width and 210 mm across the length are **unallocated perimeter residual**, not finished rooms or fixed wall offsets. Block labels express allocated planning dimensions; partitions, finishes, benches and clear usable room dimensions remain unmeasured.

The front Changing/rest + access block spans all six columns and at least two rows. Behind it, Sauna and Washing/bathing have complementary widths (Sauna 2–4 columns; Washing the remaining 4–2 columns). Each wet block has an independently adjustable length of at least two rows. Both begin at the Changing/rest boundary, so their desired door locations can meet that block. If their lengths differ, the rear leftover strip is shown as Service/unassigned, with no implied plumbing installation. There is no dedicated corridor in this first layout family. Increasing the module count extends the changing block when wet lengths are held; decreasing it restricts wet lengths before geometry is generated.

The planning function validates integer steps, changing access depth, non-overlap, complete grid coverage and fit inside the generated clear envelope. The existing System generator, full exterior area/height/span gate, connection holds and export schedule remain the same. **This is a solved allocation of planning blocks, not a buildable sauna.** The illustrated block edges are not cassette partitions or doors. Heater model and clearances, bench fit, waterproofing/thermal assembly, falls and drainage, ventilation, actual internal openings, structural support and site conditions require further decisions and design.

Studio, Workshop and Sauna use `dist/v3/presets.js` to configure the same pinned `OBTPCassette.generate` implementation. Controls follow `Version → Preset → Number of modules`: the preset selector appears directly under Version only in v3 Cassette 01. Presets alter labels and spatial allowances, shown as a proportional concept diagram; they do not add partitions, openings, plumbing or thermal layers. Switching keeps the current module count, except Sauna raises counts below eight to eight. Studio v1 remains the original independent conceptual reference; v2 remains the WikiHouse assembly, with its own unchanged 1–8 bay controls.

## Existing measurements

- v1 `enclosedFootprint` is `(length bays − porch bays) × width bays × 0.6²` m² of grid plan, and `porchFootprint` is the other grid portion. Neither measures legal total floor area.
- v2 shows `bays × 600 mm` by `4,572 mm` setting-out and does not calculate floor or regulatory area. It remains an incomplete open assembly.
- v3 previously showed `scene.length × scene.width` setting-out, `scene.clear` inside dimensions, and nominal wall height `scene.height`. There was no area, full building height or support spacing calculation.

## Current geometric checks

The v3 gate regenerates the full cassette with skins and roof for measurement even if the viewer shows a frame layer without skins. It transforms every model asset into world coordinates with the pinned System `worldBounds` API. The outside wall bounding rectangle is `(wall max X − wall min X) × (wall max Y − wall min Y) / 1,000,000`. This **conservative outside-wall plan proxy** must be positive and at most **50.00 m²**. At 18 bays its dimensions are `4,596 × 10,824 mm`, so the proxy is **49.747104 m²**; 19 bays are not generated. The internal clear area estimate uses System `scene.clear[0] × scene.clear[1] / 1,000,000`, and is **43.534620 m²** at 18 bays. It excludes partition and finish deductions.

The height gate is `(max Z of all transformed floor/wall/roof assets − min(0, min Z)) / 1,000`, with a **5.000 m** maximum; it is **2.576 m** at the 2,100 mm wall option. The renderer's exploded offsets never affect the calculation. Ground level, foundations and roof finishes are not defined, so actual legal height remains unverified.

The span gate is the maximum of each generated roof cassette's transformed transverse X width and the System wall cassette pitch. It is **4.572 m** in the present 4.572 m wide system, against **6.000 m**. Longitudinal wall cassettes continue at 600 mm joints; the 10.8 m building length does not represent an unsupported roof span. This is a geometric roof bearing screen. Foundation/support points under the floor, lateral stability and engineering capacity are not specified, so legal structural spacing and actual support adequacy remain unverified.

Lithuanian I-group classification refers to **total floor area**, not this external rectangle. The external cap is intentionally stricter for the modelled single level but cannot certify statutory area without a complete enclosed plan and any other included spaces. The status reports only the modelled dimensional checks. Classification, use, site/land conditions and SLD need separate review. There is no generated valid opening for the larger Workshop access door or the Sauna wet room; both are design holds. Do not use the program allowance labels as a completed floor plan or technical specification.

The source System module study is extended from eight to eighteen repetitions on a dedicated development branch; all source connection interfaces retain null capacity and fasteners. Tests cover 36 geometric assemblies including 18 bays and retain the prior eight-bay inspection. This extends software geometry, not structural validation.

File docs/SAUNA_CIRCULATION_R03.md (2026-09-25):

# Sauna R03 · whole-plan circulation comparison

Status: **manual spatial research**. All three studies keep the same Cassette 01 exterior, 10 module count, 600 mm coordination grid, roof bearing and regulatory dimensional screen. Colored blocks and door marks are reservations only. **No corridor partition or exterior/interior opening is generated.** Neither a second outside door nor a drawn corridor establishes a compliant escape route.

Follow-up: [R04 nominal whole-plan route study](SAUNA_ROUTE_R04.md) locates candidate side doors, a crossing band, changing seat, wet-room doors and a shower in study A. It also records the wet/dry traffic conflict that the block diagram alone cannot resolve.

Further comparison: [R05 wet-lobby plan](SAUNA_WET_LOBBY_R05.md) adds two cassette rows (12 modules total) to retain the R01 wet-room shapes and dry changing allocation while reserving a distinct 1,200 mm deep wet landing. R05 is a separate circulation study within Sauna, not a new structural preset or a solved wet assembly.

Three whole-plan Sauna circulation studies

## Fixed geometry for this comparison

- System setting-out: 4,572 × 6,000 mm; outside-wall proxy: 4,596 × 6,024 mm = **27.686304 m²**.
- Unpartitioned interior estimate: 4,182 × 5,610 mm = **23.461020 m²**.
- Planning grid: six columns × nine rows at 600 mm = 3,600 × 5,400 mm = **19.44 m²**. The 582 mm width and 210 mm length residuals have no assigned finished position. Room and corridor areas below are grid allocations, not usable finished areas.
- Coordinates are `(x columns, y rows)` from the front left. The two corridor alternatives partition along x = 2; the side-access alternative keeps the R01 block rectangles.

| Study | Circulation and outside access | Changing/rest | Washing | Sauna | Candidate exterior openings |
|---|---|---:|---:|---:|---:|
| **A · Shared dry passage** | A 1,200 mm nominal clear-route band *inside* changing/rest crosses the building; proposed entrances on opposing long facades | 6 × 5 = 10.80 m², including a 4.32 m² passage band | 3 × 4 = 4.32 m² | 3 × 4 = 4.32 m² | **2**, both on long exterior walls |
| **B · Dead-end corridor** | 2-column × 9-row side corridor = **6.48 m²**; one entrance at the front short end; rear corridor terminates internally | 4 × 3 = 4.32 m² | 4 × 3 = 4.32 m² | 4 × 3 = 4.32 m² | **1**, front end wall |
| **C · Full-pass corridor** | Same **6.48 m²** corridor; exterior access at front and rear short ends | 4 × 3 = 4.32 m² | 4 × 3 = 4.32 m² | 4 × 3 = 4.32 m² | **2**, opposite end walls |

For A, changing/rest remains `(x 0–6, y 0–5)`, Sauna `(0–3, 5–9)` and Washing `(3–6, 5–9)`. The two side doors replace the earlier R01 front entry *candidate* in this study; retaining that front door would create a third opening and is not assumed. Both wet rooms still meet changing/rest. The passage band is a circulation reservation without separating walls. The non-passage remainder of changing/rest is 10.80 − 4.32 = **6.48 m² nominal**; its seating, storage and privacy must be checked against people traversing it.

For B and C, the corridor is `(x 0–2, y 0–9)` and all rooms occupy `(x 2–6)`: changing `(y 0–3)`, washing `(y 3–6)`, Sauna `(y 6–9)`. Each room needs a candidate door in the continuous corridor partition at x = 2. A room-to-room wet door is not assumed. The nominal corridor is **1,200 mm wide**, and the effective passage will be narrower after construction. No accessibility or escape-width compliance is inferred. The Sauna is **2,400 × 1,800 mm** rather than R01's 1,800 × 2,400 mm; its 9.072 m³ nominal volume is unchanged, but the R02 heater, bench and door placements **cannot be copied by rotation without a new manual fit and ventilation check**.

## Comparison and direction

**A is the most area-efficient candidate if the goal is two outside accesses without a private hallway.** It retains the R01 wet-block geometry and the most changing/rest allowance, but through movement across a changing room can conflict with privacy, seating and wet/dry separation. Side-wall exterior openings and their effects on cassette structure and weather detailing are unsolved. The 1,200 mm band is an allocation, not a demonstrated unobstructed finished passage.

**C is the clearer choice if two distinct outside doors must connect by a dedicated, separated passage.** It costs 6.48 m² of the 19.44 m² grid and leaves only 4.32 m² each for changing, washing and Sauna. It adds two end-wall openings, a long partition with three doors, more conditioned envelope traffic and a different Sauna shape. It requires full heater and bench redesign, plus an actual structural/opening solution before the two entries are real.

**B has the same corridor area cost as C but only one outside access.** It is worth retaining if circulation must be separated from changing/rest and the site permits only a front approach. It should not be selected as a supposed escape improvement merely because its corridor is drawn; fire/occupant-use review of the dead end and route is separate.

The present R01/R02 remains a *one-entrance shared-space reference* until a circulation route is selected. A provides a less costly **two-access alternative**, C the **full longitudinal pass** the owner proposed, and B the **dead-end comparator**. Do not silently treat A's two side doors as C's front-to-rear passage; these are different site connections.

## Manual checks before making a circulation parameter

1. Choose where people actually arrive and leave the site. Two exterior doors should serve a deliberate route, not appear because a diagram can accommodate them. Fix whether users may pass through changing/rest or require a private corridor.
2. Draw door widths, swings, weather/air boundaries and a walking route in *finished* dimensions. Check changing furniture and wet-room entry manoeuvres, including route width after partition/lining build-ups.
3. Develop cassette-compatible openings at the relevant side or end walls and the long interior corridor partition. None is in the System generator; roof/floor supports, corner restraints and load paths must be checked.
4. In B/C, redraw the Sauna heater, benches, ventilation and guard in the rotated 2,400 × 1,800 mm room; in A, redo R02 after assigning residual space and real linings. Redesign washing and changing in each whole-plan option.
5. Verify actual use, occupancy, fire/egress and accessibility requirements with the Lithuanian authority/design team. This study makes **no claim** that one or two doors is required or sufficient.

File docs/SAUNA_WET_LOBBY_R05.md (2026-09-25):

# Sauna R05 · two side accesses and a wet lobby

Status: **preferred whole-plan research candidate for a private, non-residential Sauna when two side accesses are useful and changing/rest should remain dry**. This is a manual allocation and door-swing reservation, not a released room assembly, egress plan, door schedule or physical cassette opening. It develops the wet/dry conflict recorded in [R04](SAUNA_ROUTE_R04.md). The dedicated corridor alternatives remain available in [R03](SAUNA_CIRCULATION_R03.md).

R05 twelve-module Sauna with wet lobby

## Building and allocation

Use **12 of the existing 600 mm Cassette 01 modules**, retaining the same 4,572 mm setting-out width, roof bearing, structural geometry and fixed 2,100 mm nominal wall height. The current System/Studio model reports **4,596 × 7,224 mm outside-wall plan = 33.201504 m²**, **4,182 × 6,810 mm unpartitioned interior = 28.479420 m²**, modelled height **2,576 mm**, and roof support-span screen **4,572 mm**. These are the existing geometric checks; they do not establish legal area, foundation adequacy, an actual finished ceiling or permit exemption. Relative to the R04 ten-module study, the outside-wall area rises by **5.515200 m²**, remaining well below the 50.00 m² outside-wall cap.

The six-column × eleven-row coordination rectangle is **3,600 × 6,600 mm = 23.76 m²**. Coordinates use millimetres from the front west corner. The 582 mm transverse and 210 mm longitudinal residuals are still unassigned. Block rectangles are set-out allowances; internal partition and lining thicknesses must be deducted from finished room sizes.

| Block or route | X extent | Y extent | Nominal allocation |
|---|---:|---:|---:|
| Changing/rest and side-to-side route | 0–3,600 | 0–3,000 | 10.80 m², including a 1,200 mm route band at y = 450–1,650 |
| Wet lobby | 0–3,600 | 3,000–4,200 | 4.32 m²; separates the dry changing floor from wet-room door approaches |
| Sauna | 0–1,800 | 4,200–6,600 | 4.32 m²; same 1,800 × 2,400 mm allocation studied in R02 |
| Washing/bathing | 1,800–3,600 | 4,200–6,600 | 4.32 m²; reserve shower and drain for further work |

The two **outside side-door candidates** remain at x = 0 and x = 3,600, each at y = 600–1,500. A **dry-to-wet door candidate** is centered at y = 3,000, x = 1,450–2,250. It is followed by two **wet-room door candidates** at y = 4,200: Sauna x = 100–900, washing x = 2,600–3,400. Each 800 mm candidate and its swing arc is only a planning reservation. The Sauna candidate opens outward into the wet lobby in accordance with the sauna-door mechanism investigated in R04; the other swings and hardware remain under review. The three nominal wet-lobby door-swing envelopes occupy distinct X strips (100–900, 1,450–2,250, and 2,600–3,400) so they do not overlap each other in plan. **This does not prove safe simultaneous operation or usable finished circulation**; people need manoeuvring space, and walls and doors have thickness.

Keep changing seating at x = 200–1,300, y = 2,100–2,650 so it misses the central dry-to-wet door candidate. The shared outside crossing remains near the front. Wet traffic returns to the wet lobby first, crossing the separating door before reaching the changing floor. This is a more credible *spatial* wet/dry separation than R04, provided the wet lobby actually receives an appropriate waterproof floor, falls/drainage as designed, ventilation and a moisture-resistant door/partition transition. No such physical assembly is currently generated. The [Finnish Sauna Society's wet-room discussion](https://sauna.fi/saunatietoa/saunan-rakentaminen-ja-kaytto/saunan-rakennevaatimukset/) highlights how critical continuity and drying are at wet-room interfaces.

## Why 12 modules here

The added two 600 mm rows form a **1,200 mm nominal wet lobby** while preserving both R01/R02 wet-room dimensions *and* a 3,000 mm long changing/rest allocation. Trying to insert a 1,200 mm lobby into the R04 **ten-module** grid without extending the building leaves only 1,800 mm of changing/rest depth if the wet rooms remain 2,400 mm long. That smaller changing area no longer matches the tested side-to-side crossing plus seat and dry-to-wet door arrangement. The 12-module option is a purposeful smaller-than-50 m² plan, not an attempt to fill the regulatory cap.

The R02 heater's **9.072 m³ nominal Sauna allocation** remains the same because Sauna width, length and nominal height are unchanged. The heater mounting, bench support, ventilation, finished volume, safety clearances and manufacturer's current installation instructions still require verification. The R03 full-pass corridor is the stronger fallback if independent front-to-rear passage, separation from changing users, or site-specific circulation is essential; its room shapes require a new sauna fit study.

## Gate before treating R05 as solved

1. Detail and dimension the *finished* wet-lobby partition/door, corridor band, side doors and wet-room door operations. Check people passing and opening doors simultaneously, including privacy at both exterior entrances.
2. Design waterproofing, floor falls and drain strategy for washing and wet lobby, plus the transition to dry changing; verify the structural cassette floor and wall interfaces can carry it.
3. Resolve both exterior side-wall cassette openings, internal partitions, heater attachment and ventilation penetrations with engineered structural/weather/thermal details. No existing cassette output contains them.
4. Check occupancy and use-specific Lithuanian fire, accessibility, utilities, wastewater, site/land and SLD requirements separately. Two doors and dimensional compliance alone do not prove any regulatory status.

R05 is a **planning candidate**, not an automatic default for every Sauna size. The existing ten-module studies remain valid research alternatives. Parameterize this additional layout only with a hard minimum of **12 modules** and at least five 600 mm rows for changing/rest, two for the wet lobby, and two for each wet room; smaller or rearranged combinations need their own whole-plan review.

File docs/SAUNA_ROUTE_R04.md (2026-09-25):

# Sauna R04 · two side accesses through changing/rest

Status: **manual whole-plan fit study**, following [R01](SAUNA_MANUAL_PLAN_R01.md), the [R02 Sauna bench/heater reservation](SAUNA_BLOCK_R02.md) and [R03 circulation comparison](SAUNA_CIRCULATION_R03.md). R04 tests the area-efficient two-access study A. It does not generate walls, doors, service penetrations or a verified escape route. All coordinates are millimetres on the **3,600 × 5,400 mm nominal grid**, with `(0,0)` at the front west corner; the 582 mm width and 210 mm length residuals still have no finished allocation.

R04 full two-access Sauna plan study

## Block and route reservations

| Element | Nominal X extent | Nominal Y extent | Purpose |
|---|---:|---:|---|
| Changing/rest | 0–3,600 | 0–3,000 | Dry room and shared access to Sauna and washing |
| Shared crossing band | 0–3,600 | 450–1,650 | 1,200 mm planning depth between two opposing side entry candidates |
| West side entry | boundary x = 0 | 600–1,500 | 900 mm nominal exterior door reservation |
| East side entry | boundary x = 3,600 | 600–1,500 | Second 900 mm nominal exterior door reservation |
| Changing seat/storage reservation | 1,200–2,400 | 2,300–2,850 | 1,200 × 550 mm; leaves side approaches to wet doors |
| Sauna block | 0–1,800 | 3,000–5,400 | Same 1,800 × 2,400 mm R01/R02 allocated shape |
| Washing block | 1,800–3,600 | 3,000–5,400 | Same 1,800 × 2,400 mm allocated shape |
| Sauna door candidate | x = 100–900 | boundary y = 3,000 | 800 mm nominal; proposed swing **out** into changing/rest |
| Washing door candidate | x = 2,600–3,400 | boundary y = 3,000 | 800 mm nominal; proposed swing into changing/rest for clash study only |
| Shower reservation | 1,900–2,800 | 4,500–5,400 | 900 × 900 mm equipment envelope, without drain, fall or waterproofing specification |

The Sauna bench/footstep and heater rectangles from R02 fit *nominally* inside the Sauna block. Their local coordinates translate by +3,000 mm in Y. A candidate Sauna door opening outward is consistent with [Finlandia Sauna's door guidance](https://finlandiasauna.com/specifications/sauna-door/), but 800 mm width and hinge location here are **study choices**, not the manufacturer's supplied door, a Lithuanian legal requirement, or a finished hardware schedule. The manufacturer also recommends no locking mechanism; final door details require review.

The two side entrances sit wholly within the 1,200 mm crossing band, leaving 150 mm of the nominal band on either side of their 900 mm openings. West-to-east crossing is 3,600 mm across changing/rest. From that band, the west or east side strip continues to its corresponding wet-room door. Both wet-room swings are reserved within the side zones, outside the central seat's X extent; neither overlaps that **nominal** furniture rectangle. A wet-room door leaf may still reduce usable approach width while moving, and the actual finish/partition dimensions and hinge clearances have not been drawn.

**The wet/dry interface is the main conflict to solve next.** Sauna and washing users both return into changing/rest; shower traffic can carry water across the same room that holds seating and the shared side-to-side passage. R04 has no direct Sauna–washing door. Adding one would change the R02 heater/bench arrangement on their shared partition and requires a new thermal/moisture and opening design. A dry crossing is therefore an *operational intent*, not a verified dry floor. Check drainage, thresholds, splash containment and how occupants use the routes before designating the passage dry.

## Finish sensitivity and corridor comparator

The full building's current clear-width estimate is **4,182 mm**. The 3,600 mm program rectangle deliberately leaves **582 mm** transverse residual unassigned. R04 cannot claim a finished 1,200 mm passage from this grid alone; side-door jambs, internal floor build-ups, furniture and any enclosure detail must be placed and measured. The shared crossing has **no corridor partition**. Its 1,200 mm Y-band may remain available if the changing furniture and door swings stay out of it, but that condition is not yet an engineered plan.

For the dedicated R03 B/C side corridor, the same **1,200 mm is its entire allocated X width**. A hypothetical 80 mm external-wall lining and an *unselected* 100 mm corridor partition would reduce its possible clear width to `1,200 − 80 − 100 = 1,020 mm` before any further projections. This is only a sensitivity example. No claim of accessibility, egress compliance or adequate operational width follows from 1,020 mm. At ten modules the separate corridor also occupies **6.48 m²** of the 19.44 m² program grid and rotates the Sauna block, requiring a new equipment plan.

## Current conclusion and next gate

The R04 reservations demonstrate **nominal, non-overlapping positions** for two side accesses, changing seating, separate wet-room doors, shower equipment and the R02 Sauna study inside one 10-module shell. R04 remains preferable *for spatial efficiency* if through movement across changing/rest is acceptable. It loses that advantage if privacy, splash management or real door sweeps force a separated corridor or a larger wet lobby. The full-pass R03 study remains the comparator when dedicated circulation and opposite **end-wall** entries are required.

Next, choose a real partition/lining and entry-door build-up, measure the finished route and wet-door approaches, and design a wet/dry transition. The two side-wall openings are especially consequential for the cassette load path and weather envelope; no structural cuts have been approved. Actual occupancy, fire escape, accessibility, drainage and site/land conditions require use-specific review. Dimensional envelope screening alone does not establish permit exemption or approved egress.

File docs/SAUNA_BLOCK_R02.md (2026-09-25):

# Sauna block R02 · manual equipment and bench fit

Status: **candidate fit in the R01 plan, not an installed heater, released doorway, engineered bench or approved wet/thermal assembly**. R01 remains the whole-plan reference. This pass solves one program block manually before changing the shared Cassette 01 generator or propagating a sizing rule to other block combinations.

R02 nominal sauna block plan

## Reference equipment and source

For a private, non-residential auxiliary sauna study, use **Harvia The Wall SW80 HSW800400M, 8 kW electric** as the reference, not an automatic purchase specification. The [manufacturer's current product data](https://www.harvia.com/en/products/HSW800400M/the-wall-sw80-80-kw-blacksteel) gives a recommended room volume of **7–12 m³**, heater **430 × 260 × 700 mm**, **70 mm side clearance**, **80 mm minimum floor clearance**, **1,200 mm ceiling clearance**, and **2,000 mm minimum sauna height**. The manufacturer tells users to check the installation manual for updated requirements. Its published front clearance entries differ by material, so this study does **not** use a front minimum as a general walking or guard clearance. A final choice depends on finished volume, supply, installation manual, and intended operating intensity; the product is listed for household users.

[Harvia's bench guidance](https://www.harvia.com/en-US/ideas-and-trends/products/choosing-sauna-benches/) recommends 1,100–1,200 mm between the upper bench and ceiling, at least 500 mm upper bench depth, about 600 mm per seated person, and roughly 350 mm step height. This layout uses one rear bench rather than opposing benches; the same guidance says opposing benches generally need at least 2,200 mm room width, more than the 1,800 mm nominal Sauna allocation.

## Nominal plan trial, in millimetres

Local origin is at the **front west corner** of the 1,800 × 2,400 mm *allocated* Sauna rectangle. X increases east toward the outer wall; Y increases rearward. All equipment and bench rectangles are **study reservations**, measured from the nominal coordination lines rather than a finished face. Bench framing and fire protection are not designed.

| Reservation | X extent | Y extent | Purpose / check |
|---|---:|---:|---|
| Candidate entry edge | 100–900 | 0 | 800 mm nominal on the changing/rest boundary; outward swing toward changing/rest to investigate; no cut generated |
| Upper bench | 100–1,700 | 1,800–2,400 | 1,600 × 600 mm reservation across rear; two 600 mm seats are possible on paper, pending finished face/bench support |
| Foot bench/step | 100–1,350 | 1,350–1,800 | 1,250 × 450 mm reservation; final stair/foot positions and guard remain open |
| Reference heater body | 1,540–1,800 | 300–730 | 260 mm depth against east wall × 430 mm length along that wall; bracket location/penetration unapproved |
| Clear plan strip before steps | 100–1,540 | 730–1,350 | At least 1,440 mm nominal here; this is not a certified accessible route |

At y = 300–730 mm the heater projects into the room; its west face is x = 1,540 mm. The candidate entry ends at x = 900 mm on the front edge and is not aligned with the heater body. Its rear edge is 620 mm in front of the foot-bench start; the upper bench is farther away. The chosen rectangles do not overlap. Mounting the heater at its specified 80 mm floor clearance would put its 700 mm high body top near 780 mm above the unfinished floor. The *nominal* 2,100 mm room height would leave 1,320 mm above it, or 120 mm more than the listed 1,200 mm minimum. **That margin is not available for arbitrary ceiling or floor build-up**: the actual finished ceiling and installation datum have not been determined.

For an upper-bench target of 900–1,000 mm above a *finished* floor, a finished 2,100 mm ceiling would leave 1,200–1,100 mm overhead. This is a relationship to resolve with bench steps and finished levels, not an approved bench elevation. Exact seat capacity, stable bench anchorage, guard/handhold and safe door approach need drawing and physical review.

## Volume and finish sensitivity

The nominal allocated room volume is `1.8 × 2.4 × 2.1 = 9.072 m³`, inside the SW80's 7–12 m³ published recommendation. This is **not** the actual heater-sizing volume. For a *symmetric hypothetical* loss `t` millimetres at both X walls, both Y walls and ceiling, with no floor loss or glass correction, the illustrative volume is `(1800−2t) × (2400−2t) × (2100−t) / 10⁹` m³:

| Hypothetical `t` | Illustrative volume | SW80's published 7–12 m³ window |
|---:|---:|---|
| 0 mm | 9.072 m³ | Within |
| 40 mm | 8.220 m³ | Within |
| 80 mm | 7.421 m³ | Within, close to lower bound |
| 100 mm | 7.040 m³ | Borderline; rounding and floor/ceiling construction matter |

`t` is a sensitivity variable, **not** a selected wall assembly. At `t = 80 mm`, the illustrative finished plan is 1,640 × 2,240 mm. The trial's 1,600 mm bench, heater position and door reservation were drawn on *nominal* lines and must be redrawn inside that smaller finished rectangle. At `t = 100 mm` plus any finished floor loss, the heater may fall below its published minimum room volume. Glazing and uninsulated surfaces can also change the manufacturer-equivalent volume; confirm using the selected manual/calculator after finishes and glazing are defined.

The Studio control now shows an **informational nominal-volume screen** for the SW80 whenever Sauna width or length changes. It calculates `allocated width × allocated length × generated clear Z / 10⁹` in m³. A range match means only that the raw, unlined planning volume sits between 7 and 12 m³; it never sets `plan.technicalValid` true. At the R01 default (3 × 4 grid cells) it is **9.072 m³**, while 2 × 4 is **6.048 m³** (below range) and 4 × 4 is **12.096 m³** (above range). Other heater selections or a different whole-plan arrangement may be appropriate for those options. The cassette geometry's regulatory gate is independent of this product screen.

## Ventilation and whole-plan interfaces

Harvia's [electric-sauna ventilation guidance](https://support.harvia.com/hc/en-gb/articles/21953036825628-Ventilation-in-the-sauna) calls for six air changes per hour and distinguishes mechanical from gravity inlet positions. It requires low exhaust away from the heater for those arrangements, with sensor placement checked against supply air. At the nominal 9.072 m³, six changes would imply 54.432 m³/h *of room air* as a simple screening multiplication; actual fan/duct sizing, pressure and control require a ventilation design. Reserve an inlet near the heater for a gravity study and an exhaust near the bench side, then recheck against a selected ventilation method. No wall or roof penetration is generated. If exhaust goes into the adjacent washing room, Harvia states an under-door opening of at least 100 mm and mechanical exhaust are needed; R01 currently gives Sauna direct access from changing/rest, so that different route would change the plan.

## Result and next manual gate

**The nominal rectangles fit and the reference heater's published volume range contains the nominal volume.** This is enough to retain R01's Sauna allocation for a detailed section and finished-surface study. It is **not enough to mark the Sauna block technically valid**. Obtain current installation instructions, fix the actual heated/finished volume and ceiling datum, draw the partition and lining thicknesses, prove the heater/bracket can be mounted to engineered structure, and lay out the door, guard, steps and ventilation without conflict. Then recheck the washing block and changing/rest access against the whole plan. Do not turn these trial coordinates into arbitrary parametric heater placements.

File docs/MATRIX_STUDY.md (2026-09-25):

# Studio Matrix research preview

Matrix is a fourth Cassette selector entry with column and row controls. It imports the pinned System `dist/cassette/matrix.js`; Studio owns only input state, measured-dimensional screening and display. Studio, Workshop and Sauna continue to use the unchanged shared Cassette 01 generator.

The 600 × 600 mm planning cell is measured between inner perimeter wall faces. A 195 mm wall/corner depth and outside 12 mm plywood face expand the displayed wall rectangle by 414 mm in each direction. Studio measures actual generated wall part bounds, not just the cell count. It measures full model height with roof and skins, even when the frame view hides panels. Until a structural bearer is generated and checked, the **entire clear transverse width** is screened against 6 m; a short tiled cassette is not misrepresented as a supported roof span.

The preview clamps row/column controls against its conservative 50 m² outside-wall footprint and rejects out-of-range API input. At 8 × 15 it shows 49.084596 m², 43.2 m² nominal internal grid area, 2.576 m bare-frame height and a conservative 4.8 m bearing-width screen. A 8 × 16 result would exceed 50 m² and is disabled. These are dimensional screens, not certified Lithuanian statutory area, structural capacities or permit exemption. Matrix returns `valid:false`, `researchHold:true` even when its displayed geometry fits all three screens. No export/released output is offered.

Corner posts, perimeter tiles and transverse seams are research pieces without fastening schedules, foundation supports, roof finish or openings. See the pinned System `docs/cassette/MATRIX_STUDY.md` for precise scope and unresolved structural choices. Continue physical and engineering research before Matrix is presented as a valid structural preset.

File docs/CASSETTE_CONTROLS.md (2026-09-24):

# Studio-owned cassette configuration — 24 September 2026

The previous v3 embedded the complete System inspector. This conflated Studio configuration with System testing. V3 now owns its HTML, control state, rendering events and schedule presentation, following the existing WikiHouse v2 layout.

- Studio: number of modules 1–8, assembly layers, exploded view and reset. Four modules by default, 2,100 mm wall height, frame display with skins hidden. Configuration persists when switching variations.
- System: `OBTPCassette.generate`, module definitions, dimensions, placement rules, interface records, source evidence and detailed object/connection inspection.
- `system.lock.json` pins the exact System source. The build copies its `dist` and verifies that checkout before substitution. V3 loads the generator and renderer directly from that prepared dependency. It has no nested System iframe and duplicates no placement rules.
- The outer Studio variation frames remain to preserve independent v1/v2/v3 state. Studio v1 stays inside Studio. WikiHouse controls and geometry are preserved.
- System's taller-height, panel-visibility, object/connection inspection and Rhino export tools remain in System. They are not imported as Studio configuration controls.

`all` and `roof` currently show the same cassette frame because no engineered hardware is released. The matching layer selector preserves the WikiHouse interaction pattern without inventing connector meshes. Windows/doors remain on hold. Module quantities count cassettes, not screws or individual cut pieces.

Both v2 and v3 display the actual pinned System revision, substituted during preparation. The former hardcoded v2 revision was stale.

Run the development workflow on `dev/cassette-connections-studio-controls-20260924`. It prepares the exact dependency, runs both System geometry suites and tests the browser UI. The expanded test covers all 32 module/layer settings in v3, schedules, fixed comparison height, no inspector embedding, source revision display, explode/reset, switching state, WebGL, mobile overflow and the connection-report link. The workflow uploads an expiring prepared preview and screenshots; source remains durable in GitHub.

The owner authorized the System-first release followed by Studio. This continuation publishes the previously prepared Studio-owned controls after System validation. No Drive baseline update is part of this batch. Drive baseline v76 remains behind these GitHub changes. Architecture has no System dependency and is unchanged. For design evidence and physical-validation holds, read System `docs/cassette/CONNECTIONS.md` or the prepared `system-source/cassette/connections.html`.

## Inspection continuation
Studio explicitly requests revised R90 geometry from the tested System pin. Each regenerated model is registered, including end/intermediate variants when module count changes. Version is injected as the first design parameter in each variation by the parent shell; the preserved v1 file is unchanged. The separate header Variations menu is removed. Detailed part/connector/connection inspection remains in System. Software validation does not approve construction.

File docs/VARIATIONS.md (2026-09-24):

# Studio variations

V1: original reference in dist/v1, byte-identical to the pre-task version. V2: WikiHouse, the default, with existing module/stage controls and opening/end-wall holds. V3: independent OBTP Cassette 01, supplied by System through the same pinned commit relationship. V3 includes nominal end-wall framing but no released openings or weatherproof envelope.

The shell preserves each loaded iframe and its controls when switching. tools/prepare_system.py verifies system.lock.json, copies System dist and substitutes build tokens for all three variation pages. Generated System copies are not source-controlled.

No live deployment is authorized in this batch. Use the downloadable prepared preview from Drive or the non-deploying validation workflow artifact.

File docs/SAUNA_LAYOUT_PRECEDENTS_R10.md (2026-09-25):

# Sauna layouts: precedent-led shortlist (R10, 2026-09-25)

This is a planning study, not a release of partitions, openings, equipment or wet construction. Preserve the existing Cassette 01 shell and the three-function brief: hot sauna, washing, changing/rest. The matrix remains a study.

## Precedents and what they actually support

| Source | Verified observation | Transferable lesson | Limit |
| --- | --- | --- | --- |
| Lassi A. Liikkanen, [Saunologia: auxiliary spaces](https://saunologia.fi/design-of-auxiliary-spaces-for-a-finnish-sauna/) | Distinguishes hot, washing and dressing functions; offers shower ≈1.5× hot and dressing ≈2× hot as generous rules of thumb, with storage and water provision. | Size the support rooms around actual bathers, fittings and simultaneous use. | Advisory proportions, not mandatory minimums, nor proof a particular plan works. |
| [Kontio Lehtoranta](https://www.kontio.com/en/models/lehtoranta) | A Finnish manufacturer's sauna series has distinct 20, 25 and 30 m² plan drawings and differs in outside/terrace allowance. | Compare complete plan and terrace relationships, not isolated room areas. | Log structure and manufacturer floor-area terms cannot be copied into OBTP geometry or Lithuanian regulatory area. |
| [Honka Rock](https://honka.com/en/our-log-homes/all-models/rock-30-1a-en/) | Sauna and cool-off area connect to views; larger models have direct terrace access. | Treat cooling and outside access as part of the route. | Model is a different construction system and does not establish a required corridor. |
| Madeiguincho [Sauna Garden Studio](https://www.madeiguincho.pt/tiny/sauna), with the [architect-supplied project account](https://www.archdaily.com/1012355/sauna-garden-studio-madeiguincho) | Hot room and bathing room connect by a short corridor, used for a cold-water bucket. | A short link can be an active transition rather than a full-length passage. | Portuguese project, not a Nordic typology or a 3.6 m Cassette 01 precedent; its bathing room also serves changing. |

These references establish **different spatial relationships**, not an authoritative list of three Nordic archetypes. In particular, a side corridor running the full length of this narrow OBTP shell is our own proposal and needs functional testing.

## Three OBTP layout candidates

All coordinates below are *nominal planning grid* rectangles of 600 mm, before wall finishes and door construction. The shell outside-wall area for 13 and 14 bays measured by the existing generator is approximately 35.96 and 38.72 m² respectively; none of the room-area numbers below are the regulatory building area. Candidate equipment, door swings and nominal heater range pass the present spatial solver in the stated test cases, but its status does not establish finished clearances or engineered openings.

| Candidate | Route and adjacencies | Sample at equal 13-bay shell, nominal grid area | Distinct purpose |
| --- | --- | --- | --- |
| A. Serial wet route | Outside → changing → washing → sauna; sauna touches washing. | Changing 10.80, washing 7.56, hot 5.40, service/unassigned 2.16 m². | Simple room sequence, washing is the wet buffer; one entry and no hallway. |
| B. Short wet link | Outside → changing → 1.2 m-deep wet lobby → separate washing and sauna doors. | Changing 8.64, lobby 4.32, washing 6.48, hot 4.32, service/unassigned 2.16 m². | Dry changing stays separate from wet-room circulation; both wet rooms can be entered without crossing one another. |
| C. Side access | Outside → 1.2 m-wide side corridor → changing / washing / sauna individually. Optional rear exit requires a second site access. | Changing 7.20, washing 5.76, hot 4.32, corridor 8.64 m², with one outside entry. | Independent room access and an optional through route; must justify the corridor as wet transition/cooling, otherwise too much area is spent on circulation. |
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

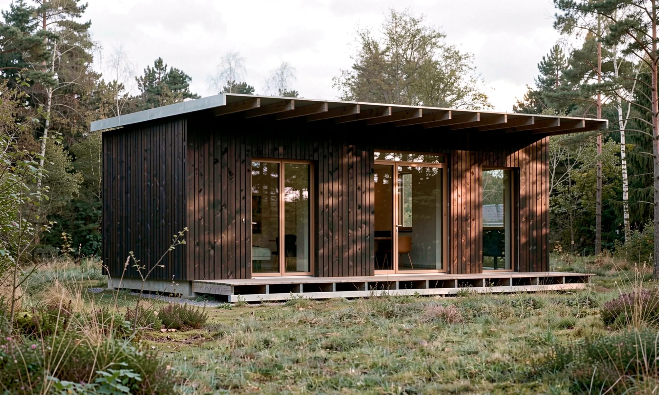
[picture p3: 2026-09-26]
dist/v3/images/studio-01.webp

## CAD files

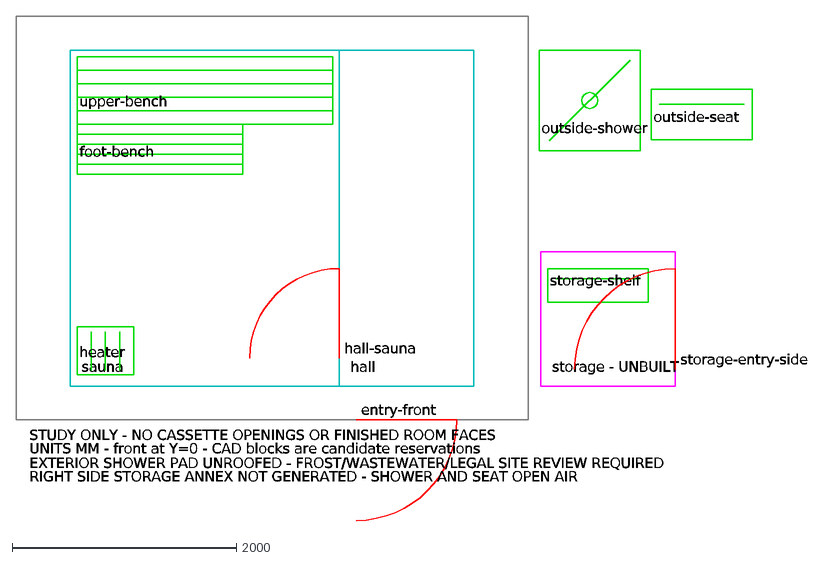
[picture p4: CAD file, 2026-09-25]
dist/v3/cad/r14/OBTP_Sauna_L_Side_Storage_Archicad_R14.dxf
sauna
hall
storage - UNBUILT
heater
upper-bench
foot-bench
storage-shelf
outside-shower
outside-seat
hall-sauna
entry-front
storage-entry-side
STUDY ONLY - NO CASSETTE OPENINGS OR FINISHED ROOM FACES
RIGHT SIDE STORAGE ANNEX NOT GENERATED - SHOWER AND SEAT OPEN AIR
EXTERIOR SHOWER PAD UNROOFED - FROST/WASTEWATER/LEGAL SITE REVIEW REQUIRED
UNITS MM - front at Y=0 - CAD blocks are candidate reservations

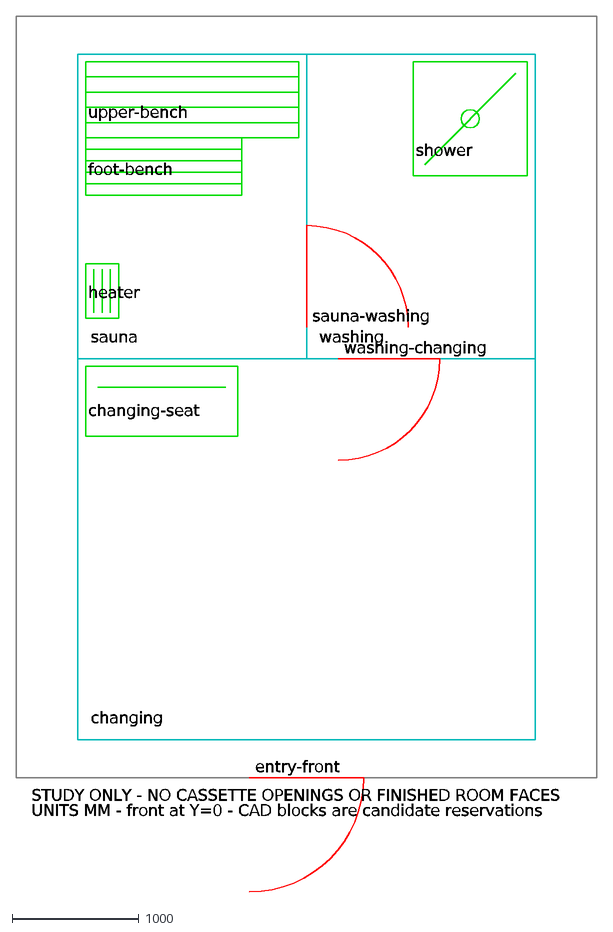
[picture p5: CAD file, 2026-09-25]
dist/v3/cad/sauna-10-shared-r06.dxf
changing
sauna
washing
heater
upper-bench
foot-bench
shower
changing-seat
sauna-washing
washing-changing
entry-front
STUDY ONLY - NO CASSETTE OPENINGS OR FINISHED ROOM FACES
UNITS MM - front at Y=0 - CAD blocks are candidate reservations

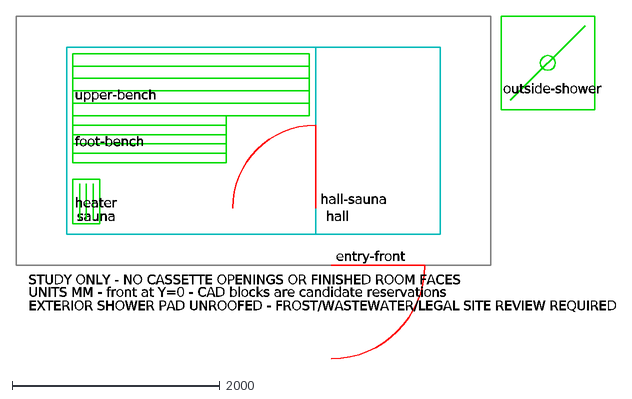
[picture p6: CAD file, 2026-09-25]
dist/v3/cad/r14/OBTP_Sauna_S_No_Storage_Archicad_R14.dxf
sauna
hall
heater
upper-bench
foot-bench
outside-shower
hall-sauna
entry-front
STUDY ONLY - NO CASSETTE OPENINGS OR FINISHED ROOM FACES
EXTERIOR SHOWER PAD UNROOFED - FROST/WASTEWATER/LEGAL SITE REVIEW REQUIRED
UNITS MM - front at Y=0 - CAD blocks are candidate reservations

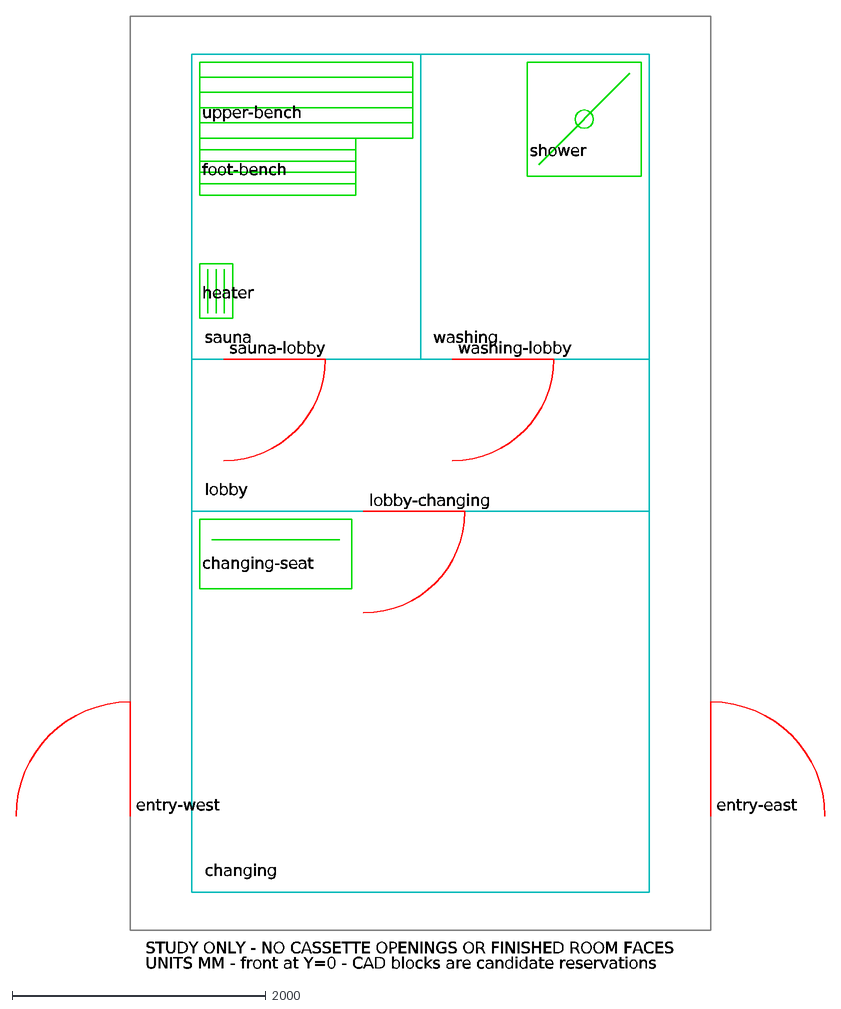
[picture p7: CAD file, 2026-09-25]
dist/v3/cad/sauna-12-wet-lobby-r06.dxf
changing
lobby
sauna
washing
heater
upper-bench
foot-bench
shower
changing-seat
sauna-lobby
washing-lobby
lobby-changing
entry-west
entry-east
STUDY ONLY - NO CASSETTE OPENINGS OR FINISHED ROOM FACES
UNITS MM - front at Y=0 - CAD blocks are candidate reservations

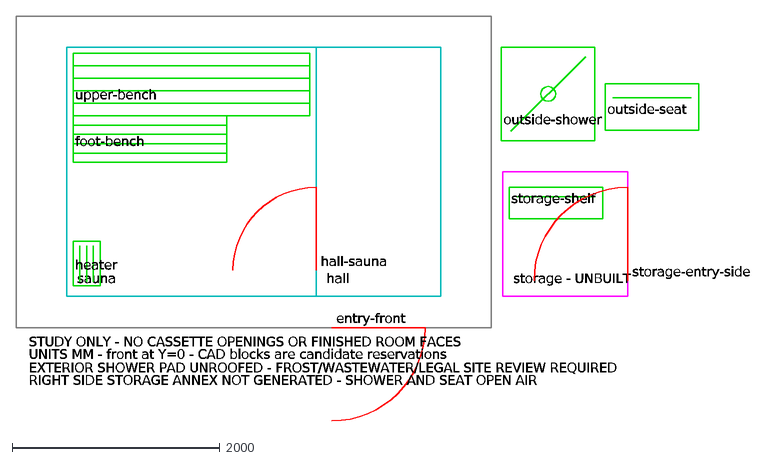
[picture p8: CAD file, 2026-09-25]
dist/v3/cad/r14/OBTP_Sauna_M_Side_Storage_Archicad_R14.dxf
sauna
hall
storage - UNBUILT
heater
upper-bench
foot-bench
storage-shelf
outside-shower
outside-seat
hall-sauna
entry-front
storage-entry-side
STUDY ONLY - NO CASSETTE OPENINGS OR FINISHED ROOM FACES
RIGHT SIDE STORAGE ANNEX NOT GENERATED - SHOWER AND SEAT OPEN AIR
EXTERIOR SHOWER PAD UNROOFED - FROST/WASTEWATER/LEGAL SITE REVIEW REQUIRED
UNITS MM - front at Y=0 - CAD blocks are candidate reservations

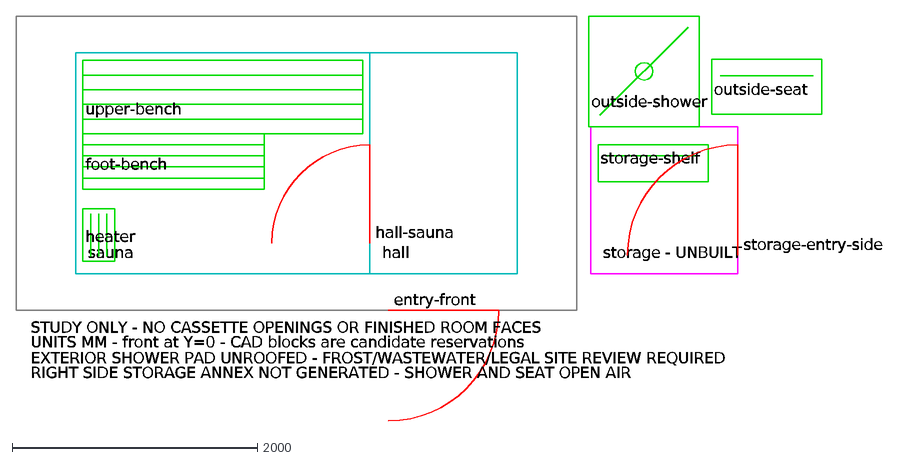
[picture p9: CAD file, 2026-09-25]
dist/v3/cad/r14/OBTP_Sauna_S_Side_Storage_Archicad_R14.dxf
sauna
hall
storage - UNBUILT
heater
upper-bench
foot-bench
storage-shelf
outside-shower
outside-seat
hall-sauna
entry-front
storage-entry-side
STUDY ONLY - NO CASSETTE OPENINGS OR FINISHED ROOM FACES
RIGHT SIDE STORAGE ANNEX NOT GENERATED - SHOWER AND SEAT OPEN AIR
EXTERIOR SHOWER PAD UNROOFED - FROST/WASTEWATER/LEGAL SITE REVIEW REQUIRED
UNITS MM - front at Y=0 - CAD blocks are candidate reservations

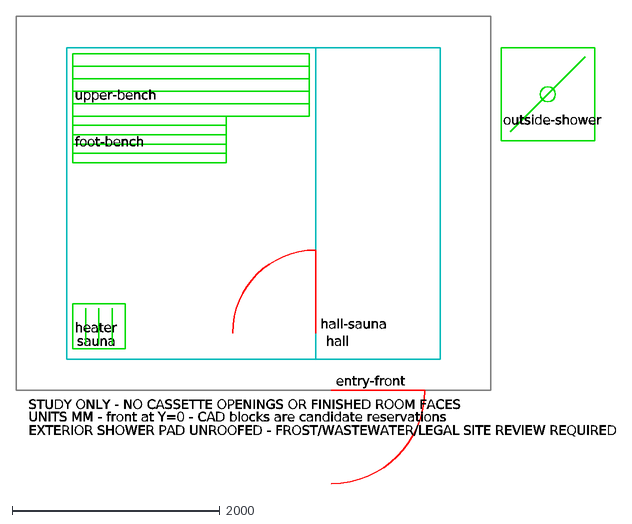
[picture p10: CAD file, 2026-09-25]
dist/v3/cad/r14/OBTP_Sauna_L_No_Storage_Archicad_R14.dxf
sauna
hall
heater
upper-bench
foot-bench
outside-shower
hall-sauna
entry-front
STUDY ONLY - NO CASSETTE OPENINGS OR FINISHED ROOM FACES
EXTERIOR SHOWER PAD UNROOFED - FROST/WASTEWATER/LEGAL SITE REVIEW REQUIRED
UNITS MM - front at Y=0 - CAD blocks are candidate reservations

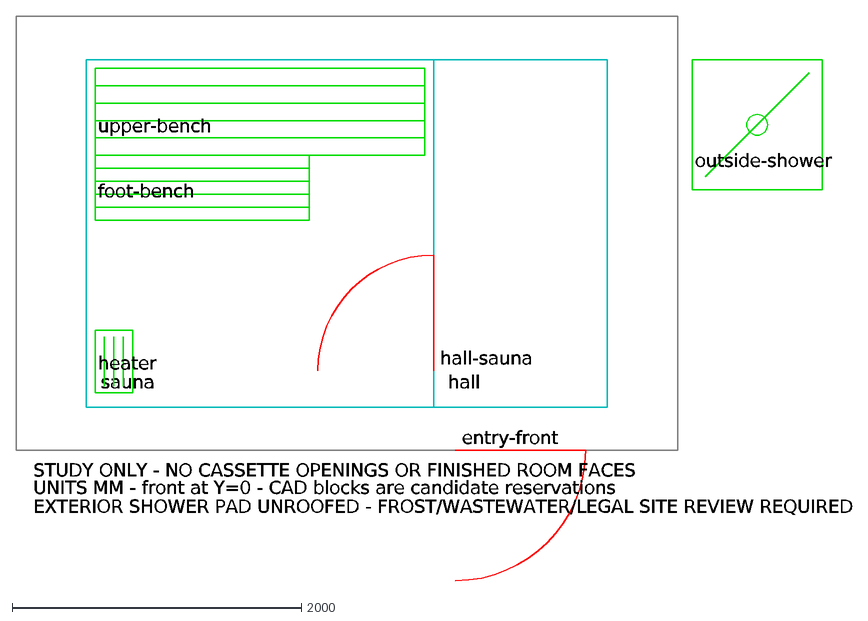
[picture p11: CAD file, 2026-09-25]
dist/v3/cad/r14/OBTP_Sauna_M_No_Storage_Archicad_R14.dxf
sauna
hall
heater
upper-bench
foot-bench
outside-shower
hall-sauna
entry-front
STUDY ONLY - NO CASSETTE OPENINGS OR FINISHED ROOM FACES
EXTERIOR SHOWER PAD UNROOFED - FROST/WASTEWATER/LEGAL SITE REVIEW REQUIRED
UNITS MM - front at Y=0 - CAD blocks are candidate reservations

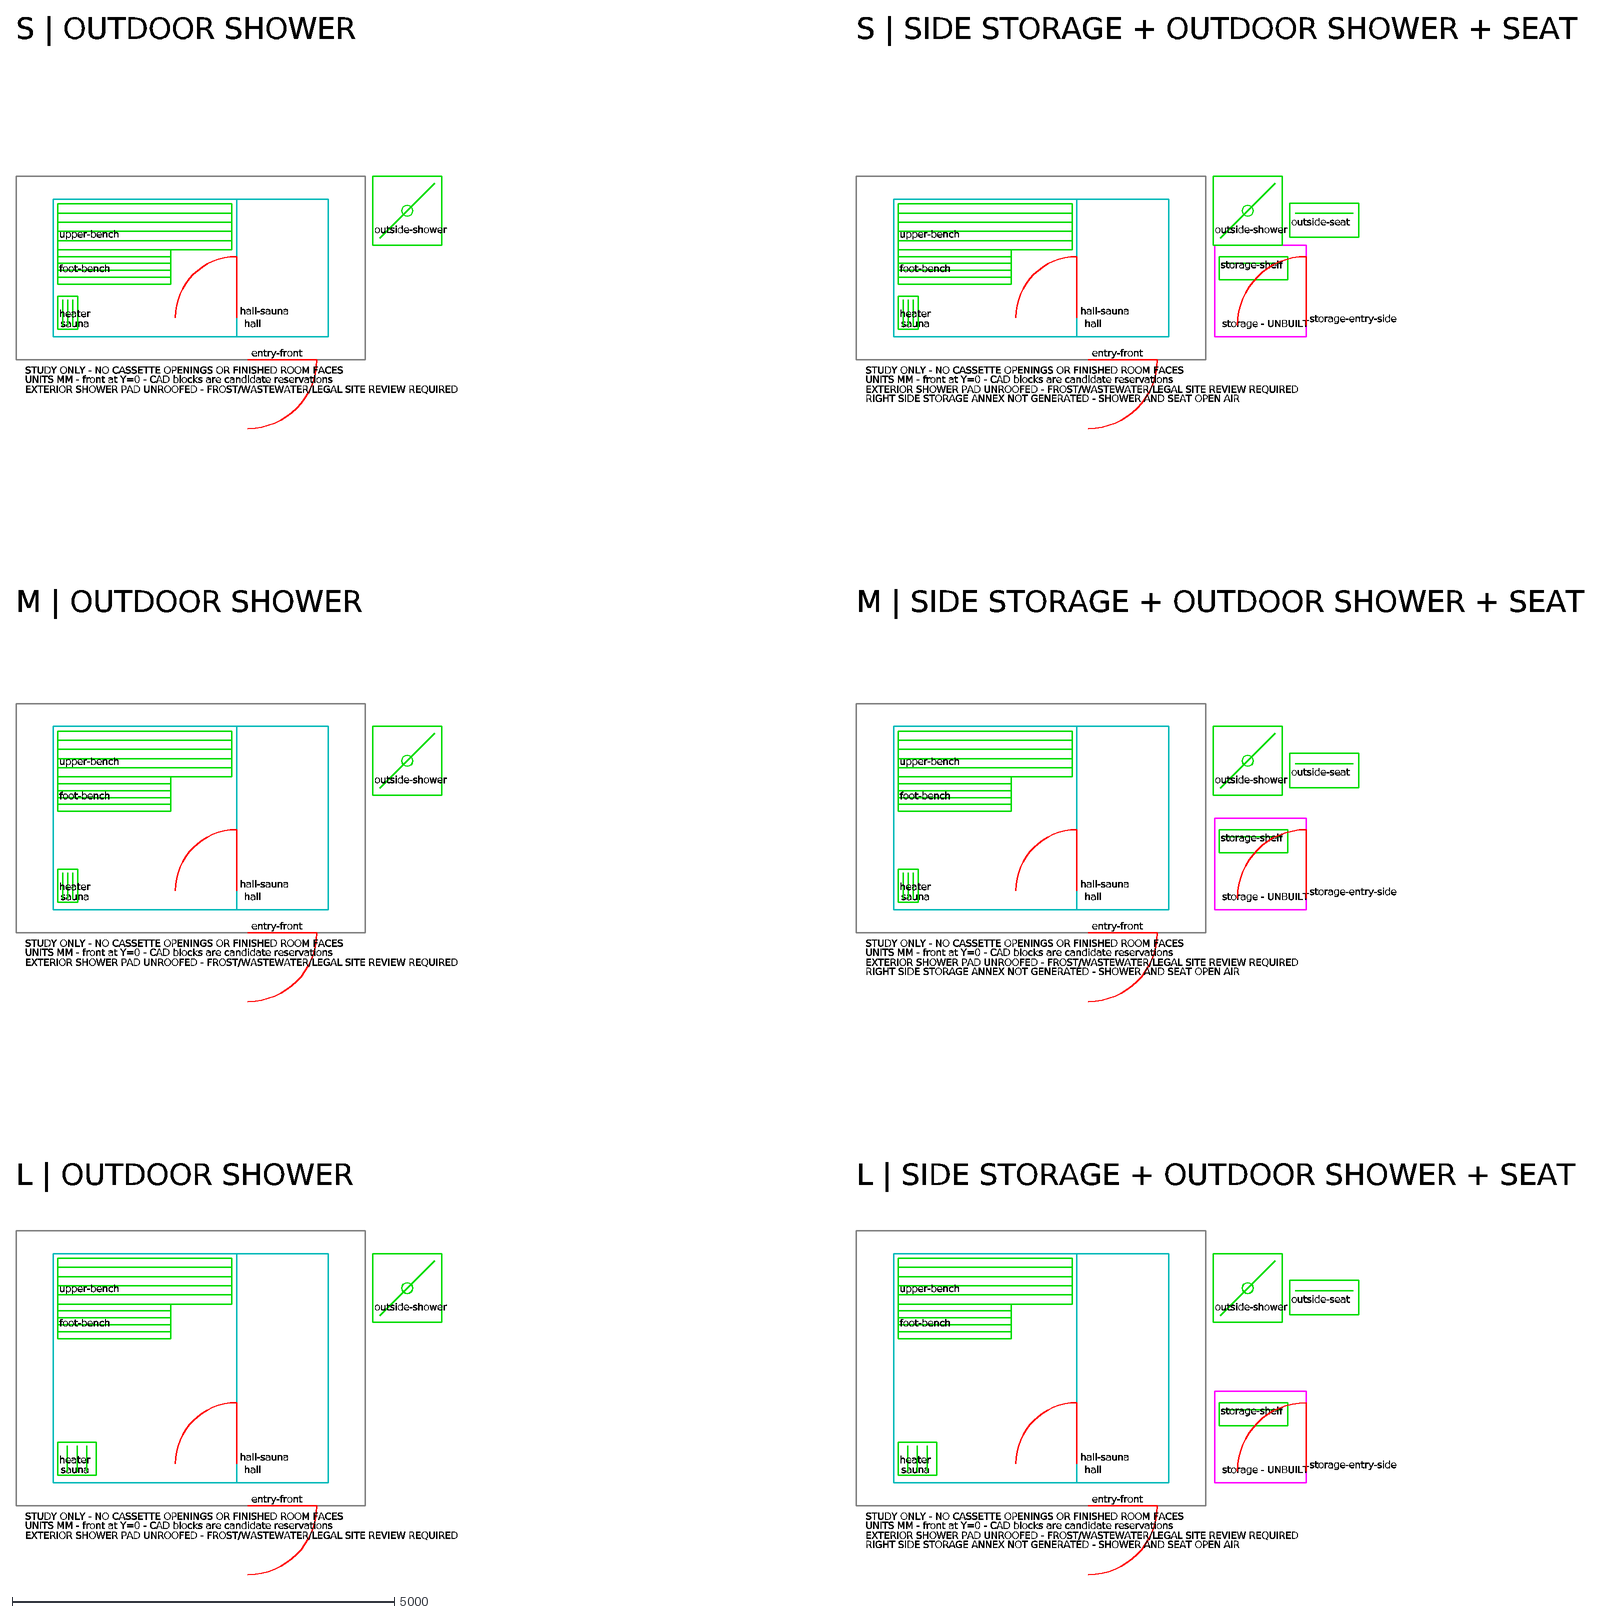
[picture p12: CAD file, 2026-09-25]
dist/v3/cad/r14/OBTP_Sauna_All_Six_Plans_Archicad_R14.dxf
sauna
hall
heater
upper-bench
foot-bench
outside-shower
hall-sauna
entry-front
STUDY ONLY - NO CASSETTE OPENINGS OR FINISHED ROOM FACES
EXTERIOR SHOWER PAD UNROOFED - FROST/WASTEWATER/LEGAL SITE REVIEW REQUIRED
UNITS MM - front at Y=0 - CAD blocks are candidate reservations
S | OUTDOOR SHOWER
storage - UNBUILT
storage-shelf
outside-seat
storage-entry-side
RIGHT SIDE STORAGE ANNEX NOT GENERATED - SHOWER AND SEAT OPEN AIR
S | SIDE STORAGE + OUTDOOR SHOWER + SEAT
M | OUTDOOR SHOWER
M | SIDE STORAGE + OUTDOOR SHOWER + SEAT
L | OUTDOOR SHOWER
L | SIDE STORAGE + OUTDOOR SHOWER + SEAT

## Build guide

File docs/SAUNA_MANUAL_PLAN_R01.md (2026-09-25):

# Sauna manual plan R01 · one representative layout for review

Status: **spatial study, not a solved construction plan or approved preset**. This is the first whole-plan reference for refining the existing Sauna blocks by hand. The Architecture project's R03 process refined one selected plan and held propagation to the other variants pending clearance and interface review. Use the same example-first discipline here; Studio and Architecture remain separate applications.

First block follow-up: [R02 Sauna equipment and bench fit](SAUNA_BLOCK_R02.md). It finds a non-overlapping **nominal** rear-bench and reference-heater arrangement, but finished clearances, manufacturer installation details and physical partition/door interfaces remain open. It does not approve the other blocks or any arbitrary parameter combination.

Whole-plan circulation follow-up: [R03 three-layout comparison](SAUNA_CIRCULATION_R03.md) considers a dry passage through changing/rest with two side accesses, a dead-end side corridor with one outside access, and a side corridor running between two outside end accesses. The corridor layouts rotate/resize the Sauna block, so R02's equipment placement does not transfer to them automatically. All outside access marks remain unbuilt.

The [R05 wet-lobby study](SAUNA_WET_LOBBY_R05.md) extends the same cassette by two 600 mm modules to separate wet-room approaches from changing/rest while retaining the R01 wet-block allocations. It is an alternative full-plan research candidate, not an approved retrofit to this 10-module reference.

[R06](SAUNA_SUBBLOCKS_R06.md) generates heater, bench, shower, changing-seat and candidate door placements from room adjacency and current dimensions. In its compact one-entry route the Sauna door faces washing, so the heater moves to the opposite wall. This replaces R02's fixed-coordinate *placement strategy* for that route; the manual R02 diagram remains an earlier comparison, not a detail to copy into R06.

## Reference envelope and block set-out

Select Cassette 01, Sauna, **10 modules**. System still generates the existing cassette. Its outside-wall plan is 4,596 × 6,024 mm = **27.686304 m²**. The unpartitioned clear interior estimate is 4,182 × 5,610 mm = **23.461020 m²**. The coordination rectangle inside it is six 600 mm columns × nine 600 mm rows = **3,600 × 5,400 mm**. The 582 mm width residual and 210 mm length residual have no assigned location or partition/finish specification. Coordinate values below are grid lines, not finished clear dimensions.

| Block | Columns (x) | Rows (y, from entry/front) | Allocated rectangle | Initial role |
|---|---:|---:|---:|---|
| Changing/rest and access | 0–6 | 0–5 | 3,600 × 3,000 mm | Entry, dry changing, shared access to both wet blocks |
| Sauna | 0–3 | 5–9 | 1,800 × 2,400 mm | Benches and heater with model-dependent clearances |
| Washing/bathing | 3–6 | 5–9 | 1,800 × 2,400 mm | Shower/washing and drainage study |

At the rear boundary of changing/rest, each wet block has a candidate doorway edge. A front exterior entrance edge is reserved, but no opening position or width is released. No dedicated corridor is used in this layout: circulation belongs to changing/rest. An internal sauna-to-washing door is not assumed. The shared sauna/washing partition must be designed for both thermal and wet exposure before any physical partition is generated.

## Manual solving order

1. **Check the whole arrangement first.** Trace a complete route from a prospective exterior entrance through changing/rest to each wet room. Reserve wall faces for supply/exhaust, drainage and service access. Mark any edge where a cassette opening would be required. The existence of a drawn edge does not approve a cut.
2. **Solve the sauna block by hand.** Choose heater type/model and bench arrangement; draw actual heater safety envelope, bench access, ventilation paths and necessary lining thicknesses inside its allocated block. If they do not fit, resize or rearrange the *whole* plan rather than just shrinking clearances.
3. **Solve washing/bathing.** Place shower/washing fixtures, drain, waterproofed floor and transition to sauna and changing/rest. Check door operation and construction thickness at both adjoining walls. Recheck the whole route and the sauna interface after every change.
4. **Solve changing/rest and services.** Locate dry changing/seating, circulation, technical equipment and access, and an exterior entry candidate. Determine whether a separate corridor is functionally necessary in this layout; if it is, draw and validate a new whole-plan option.
5. **Reconcile physical assemblies.** Replace planning boundaries with proposed partition build-ups, actual clear dimensions and credible cassette opening interfaces. Recalculate room/door/equipment clearances, external area, generated total height and structural support spacing. Reject combinations that fail. Retain opening, heater, wet-floor and structural design holds until their details are assessed.
6. **Only then generalize controls.** Record which dimensions may change in 600 mm steps without breaking the approved spatial relationships. Test the minimum, default and maximum of each range and combinations; label any unreviewed combinations as planning studies.

## Review gates before calling this layout solved

- Measured finished room sizes and usable circulation after partitions/linings; access to each block, door swings and practical changing space.
- Selected heater installation instructions, safety distances, bench arrangement and ventilation route; no universal heater clearance is assumed.
- Wet-room waterproofing, floor fall, drain/waste connection, drying route and thermal/moisture detail at the sauna–wash partition.
- Cassette-compatible entrance and internal door construction, with structural load paths maintained; no current opening is generated.
- Regulatory dimensional calculation on the actual geometry (existing outside-wall proxy ≤50.00 m²; modelled height ≤5.00 m; support-spacing screen ≤6.00 m), plus separate legal area/classification and site review.

**Decision pending from plan review:** keep integrated circulation or develop a dedicated-corridor alternative; select electric versus wood-fired heater and the level of bathing equipment before sizing its technical zone. Those choices affect plan geometry and should be made against this full reference plan, not as isolated block defaults.

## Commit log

2026-09-23 Add module-count control using System repeated open assemblies
2026-09-24 Sequence Pages publishing and pin the corrected System release
2026-09-25 Synchronize Version selector after variation switching
2026-09-25 Check Version selector state after switching
2026-09-25 Screen Sauna block against reference heater volume
    * Screen Sauna block nominal volume against R02 reference heater
    * Screen Sauna block nominal volume against R02 reference heater
    * Screen Sauna block nominal volume against R02 reference heater
    * Screen Sauna block nominal volume against R02 reference heater
    * Screen Sauna block nominal volume against R02 reference heater
    * Screen Sauna block nominal volume against R02 reference heater
2026-09-25 Link Studio v3 plan and cut views to generated cassette geometry (#13)
    * Add geometry-linked Studio plan and cut-view source
    * Add geometry-linked Studio plan and cut-view source
    * Link Studio plan and cut views with fixed camera
    * Link Studio plan and cut views with fixed camera
    * Link Studio plan and cut views with fixed camera
    * Link Studio plan and cut views with fixed camera
    * Toggle SVG hidden attribute explicitly for plan view
2026-09-25 Generate Sauna sub-block placements and reusable CAD blocks (#15)
    * Add generative Sauna sub-blocks and CAD reference
    * Add generative Sauna sub-blocks and CAD reference
    * Add generative Sauna sub-blocks and CAD reference
    * Add generative Sauna sub-blocks and CAD reference
    * Add generative Sauna sub-blocks and CAD reference
    * Add generative Sauna sub-blocks and CAD reference
    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
    [sauna-10-shared-r06.dxf, sauna-12-wet-lobby-r06.dxf]
2026-09-25 Curate Sauna indoor sizes and circulation choices (#17)
    * Curate Sauna indoor plan sizes and retain structural generator
    * Curate Sauna indoor plan sizes and retain structural generator
    * Curate Sauna indoor plan sizes and retain structural generator
    * Curate Sauna indoor plan sizes and retain structural generator
    * Curate Sauna indoor plan sizes and retain structural generator
    * Run Studio validation for pull requests to main
    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
2026-09-25 Document sauna precedent-led three-layout shortlist
2026-09-25 Move Sauna storage to hall side and export six correction plans (#20)
    * Place Sauna storage beside hall and screen annex study
    * Place Sauna storage beside hall and screen annex study
    * Place Sauna storage beside hall and screen annex study
    * Place Sauna storage beside hall and screen annex study
    * Place Sauna storage beside hall and screen annex study
    * Place Sauna storage beside hall and screen annex study
    * Place Sauna storage beside hall and screen annex study
    * Place Sauna storage beside hall and screen annex study
    * Document six Sauna side-storage correction variants
    * Document six Sauna side-storage correction variants
    * Document six Sauna side-storage correction variants
2026-09-25 Repair Sauna DXFs and offer all six layouts in one drawing (#22)
    * Serve audited Archicad DXF downloads
    * Serve audited Archicad DXF downloads
    * Generate complete audited AutoCAD 2010 sauna DXFs
    * Generate complete audited AutoCAD 2010 sauna DXFs
    * Add audited AutoCAD 2010 DXF OBTP_Sauna_S_No_Storage_Archicad_R14.dxf
    * Add audited AutoCAD 2010 DXF OBTP_Sauna_S_Side_Storage_Archicad_R14.dxf
    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
    [OBTP_Sauna_All_Six_Plans_Archicad_R14.dxf, OBTP_Sauna_L_No_Storage_Archicad_R14.dxf, OBTP_Sauna_L_Side_Storage_Archicad_R14.dxf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]
2026-09-25 Make Sauna the Studio default and pin System foundation study (#24)
    * Default to Sauna with System-backed supports and material quantity
    * Default to Sauna with System-backed supports and material quantity
    * Default to Sauna with System-backed supports and material quantity
    * Default to Sauna with System-backed supports and material quantity
    * Default to Sauna with System-backed supports and material quantity
    * Default to Sauna with System-backed supports and material quantity
    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
2026-09-25 Restore panels and simplify Sauna plan and camera views (#25)
    * Restore Sauna panels, contain source plans and add quarter-turn views
    * Pin tested System panel and coordination studies
2026-09-25 Keep assembly disclaimer in information and fit Lithuanian facade label
2026-09-25 Show plan alongside 3D and cut in customer configurator
2026-09-26 Customer R04 choices, gallery placeholders and model-derived PDF stage
2026-09-26 Pin refined R04 drawings and verify gable/gallery presentation
2026-09-26 Pin reviewed R05 drawing annotations
2026-09-26 Pin corrected R06 A3 analysis layout
2026-09-26 docs: record supplier pipeline owner decisions and agent boundaries [skip ci]
    Documentation only; preserve current deployed applications.
    skip-checks: true
2026-09-26 Pin final R07 Studio model and PDF corrections
2026-09-26 Pin Studio court with clear through passage
2026-09-26 Pin program-aware Studio analysis preparation
2026-09-26 Expose R08 winter/summer models, roof locks and heated Studio copy
2026-09-26 Verify new defaults and every cut vertex without clicking removed controls
2026-09-26 Pin final R12 supplier documentation revision
2026-09-26 studio 9120: pin R15 shared system and expose honest manufacturing comparison
2026-09-26 Complete R15 review pin and remove non-functional system selector
2026-09-26 Pin supported niche floor and align UI regression with removed selector
2026-09-26 Pin opening-component reuse and expose unchanged-footprint comparison
2026-09-26 Pin R16 shared-cut System and expose honest per-building tradeoffs
2026-09-27 Enable schedule and assembly downloads only for default Studio M
2026-09-27 Refresh downloadable GH package with stage and core-type preview sliders
2026-09-27 Restrict configurator to two fixed storage presets and generate matching assembly and parts PDFs
